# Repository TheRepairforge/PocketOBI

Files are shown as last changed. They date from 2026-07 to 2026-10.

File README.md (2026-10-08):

<div align="center">

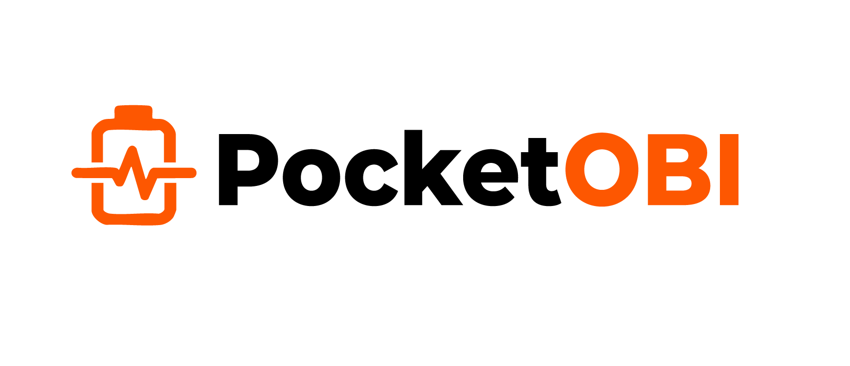
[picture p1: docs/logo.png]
PocketOBI logo


**A standalone, screen-based reader and diagnostic tool for Makita LXT (18V) batteries** — no PC required.






[Platform family](#platform-family) · [Watch it in action](#-watch-it-in-action) · [Status](#project-status) · [Features](#features) · [Hardware](#hardware) · [Build & flash](#build--flash) · [License](#license)

</div>

---

It reads cell voltages, temperatures, charge count and error/lock state, and
can reset false BMS lockouts to rescue packs that are still good.

PocketOBI is a standalone **OBI client**: it speaks the same Makita OneWire
protocol documented by the [Open Battery Information](https://github.com/mnh-jansson/open-battery-information)
project, but as a self-contained handheld device with a TFT screen and a
rotary encoder instead of a computer.

Created by **The Repair Forge** — follow the build on YouTube:
https://www.youtube.com/channel/UCQL_-pcIEkrDPyljl3QPzcw

## Platform family

PocketOBI started on Makita LXT (18V) — this repo — and is growing into a small
family of standalone OBI-client readers, one per battery platform. Same
hardware/UI approach, same protocol-first philosophy, different pack connector
and decode tables under the hood.

| Platform | Tag | Status |
|---|---|---|
| Makita LXT (18V) |  | ✅ shipping — this repo |
| Makita XGT (40V) |  | 🔜 planned |
| HiKOKI (BSL) |  | 🚧 in progress |

Each sibling gets its own repo once it's ready to publish; this table (and its
own release badge) grows as they ship.

## 📺 Watch it in action

PocketOBI v2 on YouTube (https://youtu.be/8Qe2dTXrJ8g)

The **v2** walkthrough — the new interface, the traffic-light verdict and the staged
repair wizard in action:
**https://youtu.be/8Qe2dTXrJ8g**

Original build & protocol deep-dive — how it works, the reverse-engineering, and a live demo:
**https://youtu.be/57KsQQ7-Qd0**

## Project status

Current release: **[v2.3.0](https://github.com/TheRepairforge/PocketOBI/releases/latest)** — see [CHANGELOG.md](CHANGELOG.md) for details.

The **v2** interface: a 2×2 launcher, a paged Battery view, a
traffic-light verdict and a staged Repair wizard, multilingual EN/FR/DE/ES, on a
single-source build. Validated on real BL18xx packs. Since **v2.2** the same firmware
also runs on the **CYD** (ESP32-2432S028R) with a touch UI, as an
[alternative board](#alternative-board-cyd-esp32-2432s028r). Since **v2.3** there is a
[Japanese build](#日本語--japanese--help-wanted) and every release ships ready-to-flash
binaries. Feedback and test reports
(especially serial logs from real packs) are very welcome.

> ⚠️ **Safety first.** These packs contain lithium cells and up to ~21 V on
> B+. **Never connect B+ to the ESP32.** Resetting a BMS error only helps a
> pack whose cells are actually healthy (a false lockout). Do **not** force a
> pack with a genuinely bad/low cell back into service — it is a fire risk.
> Use this tool at your own risk.

## Features

- **Standalone V2 interface** — a 2×2 launcher (Battery / Repair / Tools / About)
  driven by the rotary encoder (+ a secondary back button: short = back, long = home);
  it jumps straight to the Battery view when a pack is connected.
- **Battery view, paged** (turn the encoder): Overview / Health / Identity.
  - *Overview*: per-cell voltage bars (green / yellow / red), pack voltage, spread.
  - *Health*: our own cycle-based Condition estimate, over-discharge / over-load wear
    counters, cell min/max + spread, both temperature sensors + spread.
  - *Identity*: model, charge count, manufacturing date, capacity, and the pack
    **serial number** (ROM ID in Makita 16-char hex format).
- **Traffic-light verdict** — HEALTHY / REPAIRABLE / REAL FAULT (plus an orange
  "possible HW fix" tier). One verdict, computed from a single source and shown
  identically on the Battery tile, the screens and the Repair wizard.
- **Repair wizard** — a staged, feasibility-first check: comms → hardware faults
  (broken sense wire / weak group / imbalance / thermistor, each naming the group or
  sensor) → lock + prognosis (false lockout "should hold" vs a memorised fault
  "unlikely to hold"). A hardware fault blocks the unlock; the prognosis reads as
  guidance, never a guarantee.
- **Unlock / repair** — rewrites the frame to lift a *false* charger lockout on a
  pack whose cells are healthy: clears the charger-lock nybble, recomputes the
  charger-validated checksums, writes the frame back. Never forces a genuinely bad
  pack back into service. See below.
- **Error reset** with before → after feedback (full test-mode + power-cycle sequence).
- Automatic detection of standard vs older **F0513** BMS generations.
- **Multilingual UI** — English, French, German, Spanish, and **Japanese** in the
  Japanese build (see below).
- **PC bridge mode** — acts as a USB↔OneWire adapter (drop-in ArduinoOBI), so a desktop
  app works through PocketOBI: the original *Open Battery Information* app, or our own
  companion **[PackScope](https://github.com/TheRepairforge/PackScope)** — saved history,
  a health estimate and a guided repair workflow. Dual use: standalone tester **and** PC adapter.
- Tools: pack LED test, error reset, raw debug view (ROM ID + message frame).

## 日本語 / Japanese — help wanted

A **Japanese build** of the firmware shows the whole UI in Japanese (Settings → Language →
JA). Its text is a **first draft that no native speaker has reviewed**: expect stiff phrasing
and some wrong repair vocabulary. I do not read Japanese, so I cannot judge it myself.

**If you read Japanese and work on power tools or batteries, I would love your help.**
All the text is one file, [`strings_ja.h`](strings_ja.h): one line per message, with the English
next to it. Open a pull request, or an [issue](../../issues/new?template=translation.yml)
with corrections, no Git needed. You can see your text on every screen without a board with
[`tools/hostsim`](tools/hostsim/README.md). Rules and details: [docs/TRANSLATING.md](docs/TRANSLATING.md).

Build it with `pio run -e esp32-c3-ja` (or `cyd-ja`), or in the Arduino IDE by putting
`#define ENABLE_CJK 1` in a local `board_local.h` next to the sketch.

## Architecture

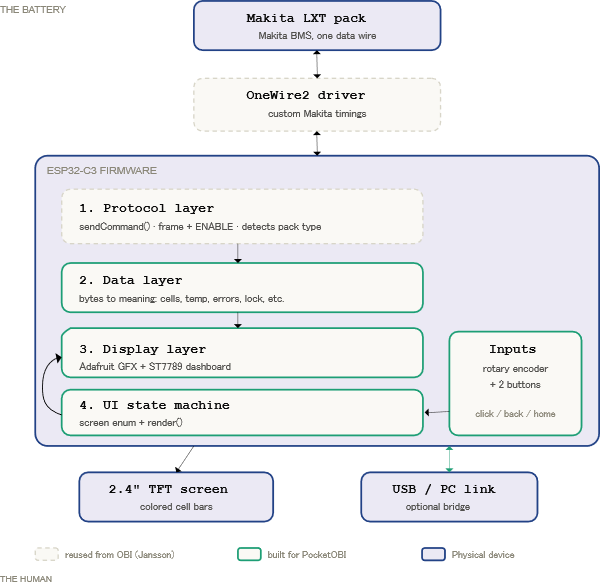
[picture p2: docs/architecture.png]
PocketOBI architecture diagram
[](docs/architecture.png)

*(click for full size — full-resolution file in [`docs/architecture.png`](docs/architecture.png))*

From the battery up: the Makita pack speaks over a single data wire; the bundled
**OneWire2** driver (reused from OBI) handles the custom Makita bit timings; the
ESP32-C3 firmware is layered — protocol (frames + ENABLE, pack-type detection),
data decode (bytes → cells / temperature / errors / lock), display (Adafruit GFX
+ ST7789) and a small UI state machine — driving the TFT and, optionally, a USB
PC bridge.

## Hardware

| Component | Notes |
|---|---|
| ESP32-C3 SuperMini | any ESP32-C3 board with native USB |
| 2.4" SPI TFT, ST7789 (240×320) | + integrated EC11 rotary encoder module |
| Makita BL1830 LXT adapter | clips onto the 18V pack |
| 2 × 470 Ω resistors | pull-ups for DATA and ENABLE (4.7 kΩ also works with short wiring) |
| USB-C power (power bank/charger) | powers the tool — NOT the battery |

### Wiring

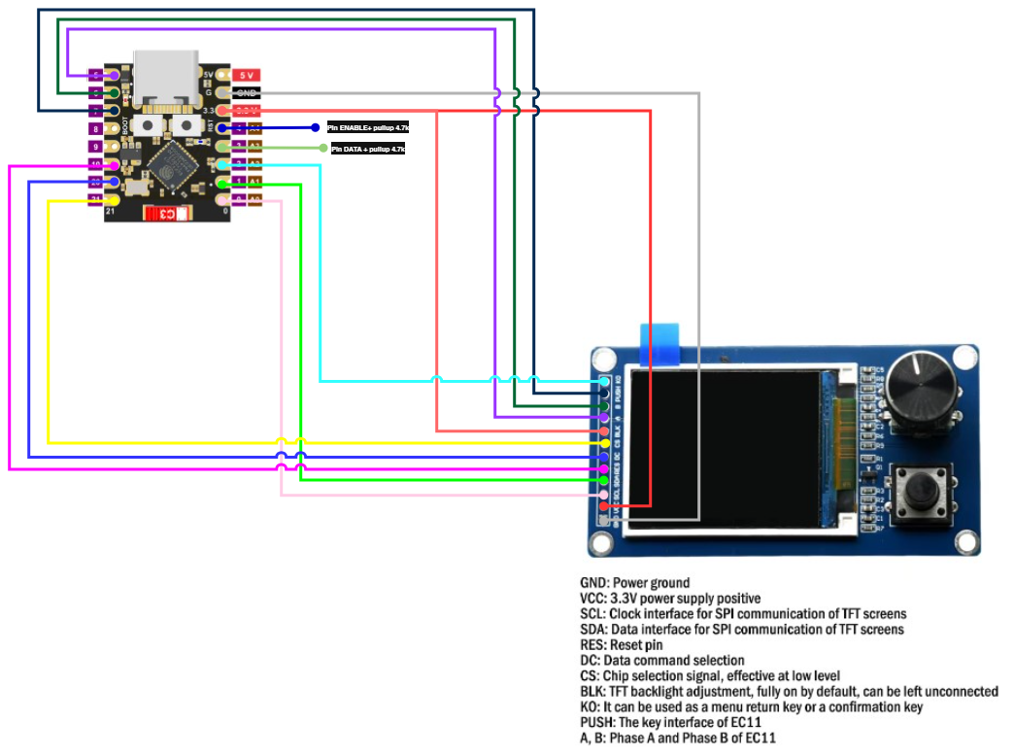
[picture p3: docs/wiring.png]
PocketOBI wiring diagram
[](docs/wiring.png)

*(click for full size — full-resolution file in [`docs/wiring.png`](docs/wiring.png))*

**Display + encoder module (2-in-1 TFT + EC11):**

| ESP32-C3 | Module pin | Role |
|---|---|---|
| GPIO0  | SCL  | SPI clock |
| GPIO1  | SDA  | SPI data (MOSI) |
| GPIO10 | RES  | reset |
| GPIO20 | DC | data / command select |
| GPIO21 | CS | chip select (active low) |
| 3.3 V  | VCC  | logic power |
| 3.3 V  | BLK  | backlight (or leave unconnected = always on) |
| GND | GND  | ground |
| GPIO5  | A | encoder phase A |
| GPIO6  | B | encoder phase B |
| GPIO7  | PUSH | encoder push button |
| GPIO2  | KO | secondary button (short = back, long = home) |

**Battery adapter (Makita LXT connector):**

| ESP32-C3 | Battery pin | Role |
|---|---|---|
| GPIO3 + 470 Ω pull-up to 3.3 V | Pin 2 — **DATA** | OneWire data |
| GPIO4 + 470 Ω pull-up to 3.3 V | Pin 6 — **ENABLE** | enable (active high) |
| GND | main **B-** terminal | ground (sturdier than signal pin 5; same ground) |
| — | Pin 1 — **B+ (18 V)** | **NEVER CONNECT** |

Notes:
- **Pull-ups:** **470 Ω** is the bench-validated value: on 3.3 V logic the pack
  loads the DATA line near the input threshold, and 4.7 kΩ was marginal with
  breadboard wiring. 4.7 kΩ (the upstream OBI value) should be fine with short,
  clean wiring. ENABLE is a driven output; 470 Ω there just keeps a single-value BOM.
- ⚠️ **Identify DATA/ENABLE by the ESP32 silkscreen labels ("3" / "4"), not by
  the adapter's connector position.** Some AliExpress adapters number their orange
  connector from the opposite end, so DATA can land on what looks like "plot 6"
  and ENABLE on "plot 2". Wrong plots = no comms (present = 0, all-`FF`/`00`).
- Power the tool from **USB-C**, never from the Makita pack (B+ is 18 V, and the
  BMS can cut its own output on error).

A carrier PCB has been **fabricated and bench-validated**. The fabrication files
(Gerbers, schematic PDF, BOM) and ordering notes are in [`hardware/`](hardware/); the
wiring and pinout reference stays in [HARDWARE.md](HARDWARE.md).

### Alternative board: CYD (ESP32-2432S028R)

Since v2.2 the firmware also builds for the "Cheap Yellow Display" (dual-USB / ST7789
revision, XPT2046 resistive touch). Same logic, same screens; the UI is driven by
touch instead of the encoder, with on-device touch calibration (Settings > Calibrate).
The ESP32-C3 build above remains the reference product.

The whole pack connection fits on the CYD's 4-pin **CN1** header:

| CN1 | Battery pin | Role |
|---|---|---|
| IO22 + 470 Ω pull-up to 3V3 | Pin 2 — **DATA** | OneWire data |
| IO27 + 470 Ω pull-up to 3V3 | Pin 6 — **ENABLE** | enable (active high) |
| GND | main **B-** terminal | ground |
| 3V3 | — | feeds the two pull-ups |
| — | Pin 1 — **B+ (18 V)** | **NEVER CONNECT** |

Step-by-step guide (build, flash, wiring, first read): [docs/CYD_GUIDE.md](docs/CYD_GUIDE.md).
Board selection and build notes: [CYD_NOTES.md](CYD_NOTES.md).

## Build & flash

### Flash a prebuilt binary (no build)

Each [release](https://github.com/TheRepairforge/PocketOBI/releases/latest) carries one
merged image per board and language, flashed at address `0x0`:

| File | Board |
|---|---|
| `PocketOBI-vX.Y.Z-esp32-c3.bin` | ESP32-C3 (the reference product) |
| `PocketOBI-vX.Y.Z-cyd.bin` | CYD (ESP32-2432S028R) |
| `PocketOBI-vX.Y.Z-esp32-c3-ja.bin` / `-cyd-ja.bin` | Same boards, Japanese build |
| `PocketOBI-vX.Y.Z-cyd-ili9341.bin` | CYD fitted with an ILI9341 panel (mirrored image on the plain CYD build, see the [CYD guide](docs/CYD_GUIDE.md)) |

```bash
pip install esptool
esptool --chip esp32c3 write_flash 0x0 PocketOBI-vX.Y.Z-esp32-c3.bin   # ESP32-C3
esptool --chip esp32 write_flash 0x0 PocketOBI-vX.Y.Z-cyd.bin          # CYD
```

Older esptool versions are called `esptool.py`. Check a download against `SHA256SUMS.txt`
from the same release. The `parts-*.zip` files hold the separate bootloader, partition
table and application images for tools that want them.

### Arduino IDE

1. Install the **ESP32 board package** (Espressif) via the Boards Manager.

   > **Use a stable core (3.x).** PocketOBI is built and tested against the
   > **stable ESP32 core 3.x** (2.0.x also works). Avoid the **alpha/dev
   > releases** (e.g. `4.0.0-alpha1`): they build fine but flood the console
   > with harmless `-Wdeprecated-declarations` / `-Wmissing-field-initializers`
   > warnings coming from *the core itself* (`esp32-hal-ledc.c`, `Esp.cpp`, …),
   > not from PocketOBI. If you see those warnings, it is the alpha core, not a
   > bug here — select a 3.x version in the Boards Manager.

2. Install these libraries via the Library Manager:
   - Adafruit GFX Library
   - Adafruit ST7735 and ST7789 Library
   - RotaryEncoder (by Matthias Hertel)
   - (OneWire2 is bundled in this repo — nothing to install.)
3. Open `PocketOBI/PocketOBI.ino`.
4. Board: **ESP32C3 Dev Module**, USB CDC On Boot: **Enabled**.
5. Upload.

**CYD build (Arduino IDE):** also install **XPT2046_Touchscreen** (Paul Stoffregen,
v1.4), select **ESP32 Dev Module**, and put a `board_local.h` next to the sketch
containing `#define POCKETOBI_BOARD BOARD_CYD` (the file is gitignored).

> Note: Arduino requires the sketch to live in a folder named `PocketOBI`.
> If you downloaded a ZIP (GitHub adds a `-main` suffix), rename the inner
> sketch folder back to `PocketOBI` before opening it.

### PlatformIO (VS Code)

The `platformio.ini` at the repo root builds the **same sources** the Arduino IDE
uses, straight from the sketch folder — no separate project, no copy to keep in sync:

```bash
pio run -e esp32-c3             # build the ESP32-C3 product
pio run -e esp32-c3 -t upload   # build + flash
pio run -e cyd -t upload        # CYD alternative board
pio device monitor              # serial monitor (115200)
```

There is one env per board; always pass `-e`, otherwise `pio run -t upload` builds and
flashes every env in turn. The `esp32-c3` env uses `esp32-c3-devkitm-1` (works for the
ESP32-C3 SuperMini); change `board` in that env for a different ESP32-C3 module.

## Usage

Power the tool over USB, connect DATA / ENABLE / GND to the pack (never B+),
and it reads automatically. Turn the encoder to navigate, click to select (on the CYD: tap).
If the home screen shows "No battery found", check wiring and use
Menu → Read battery. "Comm error" / all-`0xFF` means the pack's BMS is not
responding (dead, or not an OBI-compatible pack).

Trouble reading a pack, or connecting the PC bridge? See
**[TROUBLESHOOTING.md](TROUBLESHOOTING.md)** — a step-by-step guide to wiring,
no-comms and bridge-connection faults.

## Unlock / repair

Some packs refuse to charge even though their cells are healthy and balanced:
the BMS stores a frame that trips the charger's lock. The Makita charger only
validates **three** fields of the 32-byte frame:

- **nybble 34** (byte 17, low) — the charger lock, must be `0`;
- **CS0** (nybble 41) — `sum(nybbles 0–15) & 0x0F`;
- **CS2** (nybble 43) — `sum(nybbles 32–40) & 0x0F`.

The status byte (byte 19, e.g. `0xA5`) and the reported temperatures are **not**
part of that check. The battery's own internal lock additionally checks **CS1**
(nybbles 16–31, per the rosvall protocol docs), so the repair recomputes all
three checksums. The Unlock / repair menu entry clears nybble 34, recomputes
CS0/CS1/CS2, writes the frame back (arm → write → store) and clears the internal
error register. The failure code (nybble 40, e.g. `0xF` = dead) is **never**
cleared — a genuinely dead pack is not forced back into service. Manufacturing/status bytes are never touched, and if the frame
is already valid no write is performed.

> ⚠️ This **writes to the BMS flash** and is gated behind a confirmation screen.
> It only clears a *false* charger lockout on an otherwise-healthy pack; it never
> overrides the BMS's own fault protection. Never use it to force a pack with a
> bad or low cell back into service.

## Note on temperature units

Temperatures are decoded as **1/10 K** (`T_C = raw / 10 - 273.15`). This is now
corroborated by four independent sources: the
[rosvall protocol docs](https://codeberg.org/rosvall/makita-lxt-protocol), the
obi-esp32 encoding, and both sides of the
[m5din-makita](https://github.com/no-body-in-particular/m5din-makita) fork — its
reader (`(raw / 10) - 273.15`) *and* its BMS emulator (`(T_C + 273.15) * 10`).
The original Open Battery Information app decodes the same field as
**Celsius x100**; that appears to be the outlier. The unit is still not stated in
any official Makita document, so treat the absolute value as approximate, but the
1/10 K interpretation is the well-supported one. The dependable signal is *relative*: the
two sensors are shown side by side (e.g. `28/31`, and in red when a value is
implausible), so a reading that is far off or that disagrees strongly with the
other flags a likely faulty thermistor.

The two sensors are reported by the BMS over the data line (there is **no
separate thermistor pin** on the connector). The original protocol simply labels
them **"Sensor 1"** and **"Sensor 2"** — **which reading is the cell sensor vs the
MOSFET sensor is not documented**, and their physical placement on the BMS board
is unknown. PocketOBI just shows both values; do not assume which is which.

## Versioning

See [CHANGELOG.md](CHANGELOG.md). The current version is shown on the
Version / info screen and defined as `FW_VERSION` in `pocketobi.h`.

## Credits

- **Open Battery Information** by **Martin Jansson** — the original project that
  documents the Makita protocol and provides the OneWire2 library.
  https://github.com/mnh-jansson/open-battery-information (MIT)
- ESP32-C3 wiring reference: the `obi-esp32` port by appositeit.
- Root protocol reverse-engineering: the
  [rosvall/makita-lxt-protocol](https://codeberg.org/rosvall/makita-lxt-protocol)
  documentation (frame byte/nybble map, the three checksum ranges, per-type
  command sets) — the origin much of the LXT decoding traces back to.
- Unlock / frame-repair research: the
  [synrais/Makita-LXT-Battery-Monitor-Unlocker](https://github.com/synrais/Makita-LXT-Battery-Monitor-Unlocker)
  project, which documented the frame byte map, the CS0/CS2 checksums, the
  charger-lock nybble and the arm/write/store opcodes. That repository ships with
  **no license** (all rights reserved), so **none of its code is used here**;
  PocketOBI's unlock feature is a clean-room reimplementation from those
  (unprotectable) protocol facts only, cross-checked against real battery dumps.

## License

PocketOBI is licensed under the **PolyForm Noncommercial License 1.0.0** — free to
use, modify, and share for any **noncommercial** purpose (personal, hobby, repair,
education, research). Commercial use requires a separate license. See [LICENSE](LICENSE).

Bundled and reused third-party components keep their own licenses — see
[THIRD-PARTY.md](THIRD-PARTY.md). The bundled OneWire2 library and the upstream
Open Battery Information project remain under the MIT license.

---

<div align="center">

```
  ___         _       _    ___  ___ ___ 
 | _ \___  __| |_____| |_ / _ \| _ )_ _|
 |  _/ _ \/ _| / / -_)  _| (_) | _ \| | 
 |_| \___/\__|_\_\___|\__|\___/|___/___|
=-=-=-=-=-=-=-=-=-=-=-=-=-=-=-=-=-=-=-=-=-=-=
       . No Guru Meditation required .
=-=-=-=-=-=-=-=-=-=-=-=-=-=-=-=-=-=-=-=-=-=-=
```

Built by **[The Repair Forge](https://www.youtube.com/channel/UCQL_-pcIEkrDPyljl3QPzcw)**

</div>

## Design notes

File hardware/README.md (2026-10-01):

# PocketOBI — hardware

Fabrication files for the PocketOBI carrier PCB: a small 2-layer board that carries the
ESP32-C3 SuperMini, the display + encoder module header, the Makita LXT battery connector
and the two pull-up resistors. **This is the board only — it does not restate the
wiring/pinout, which lives in [`../HARDWARE.md`](../HARDWARE.md) and the main
[README](../README.md).**

> ⚠️ Same safety rule as the firmware: **never connect battery B+ (18 V) to the ESP32.**

## Revision

First fabricated and **bench-validated** revision — Gerbers dated **2026-08-05**
(`gerber/PocketOBI-HW-gerbers-2026-08-05.zip`). This is the exact set that was ordered.

> **Schematic PDF updated 2026-09-30; PCB and Gerbers unchanged.**

## What's here

| File | What it is |
|---|---|
| `gerber/PocketOBI-HW-gerbers-2026-08-05.zip` | ready-to-order Gerbers + drill — upload this |
| `gerber/*.gbr`, `*.drl` | the same layers, extracted, for inspection |
| `PocketOBI-HW-schematic.pdf` | the schematic — to read and troubleshoot, not editable |
| `PocketOBI-HW-BOM.csv` | bill of materials (6 parts) |

## Order the board

Upload `gerber/PocketOBI-HW-gerbers-2026-08-05.zip` to a fab house (JLCPCB, PCBWay, …).
Defaults are fine: **2 layers**, 1.6 mm, HASL, any colour — no controlled impedance and no
special stackup.

## Bill of materials

| Ref | Part | Note |
|---|---|---|
| U1 | ESP32-C3 SuperMini | any ESP32-C3 board with native USB |
| M1 | 1×12 pin socket, 2.54 mm | header for the 2-in-1 TFT + EC11 module |
| Battery_Interface1 | JST-PH 6-pin, vertical | to the Makita LXT adapter |
| Battery_GND1 | 2-pin screw terminal, 3.5 mm | battery B- |
| R1, R2 | 4.7 kΩ resistor, THT | DATA and ENABLE pull-ups (470 Ω also works) |

Full list: [`PocketOBI-HW-BOM.csv`](PocketOBI-HW-BOM.csv). Everything is through-hole and
hand-solderable. (R1/R2 export as a generic value `R` in the CSV — they are **4.7 kΩ**.)

## Assembly

Solder the through-hole parts, then seat the ESP32-C3 and the display + encoder module on
the headers. **Wiring, pinout and the DATA/ENABLE identification gotcha are in
[`../HARDWARE.md`](../HARDWARE.md)** — not repeated here so the two never drift.

## Enclosure

A 3D-printable enclosure is on Printables:
**<https://www.printables.com/model/1833871-pocketobi-makita-18v-lxt-battery-diagnostic-tool-c>**
— "PocketOBI – Makita 18V LXT Battery Diagnostic Tool", by The Repair Forge. The STL files
are not committed here; download them from the Printables page.

## License

The hardware design files in this folder (Gerbers, schematic, BOM) are licensed
**CC BY-NC-SA 4.0** — see [LICENSE](LICENSE). The firmware is licensed separately under the
PolyForm Noncommercial License 1.0.0 (PolyForm is a software licence, so the board files use
the Creative Commons equivalent).

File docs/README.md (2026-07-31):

# docs

Images referenced by the main [README](../README.md).

Place these two files here, with **exactly** these names:

- **`architecture.png`** — the software / architecture block diagram
  (battery → OneWire2 → firmware layers → screen / PC link).
- **`wiring.png`** — the physical wiring diagram
  (ESP32-C3 SuperMini ↔ 2.4" TFT + EC11 module, with the DATA/ENABLE pull-ups).

Any resolution works; the README shows them as clickable thumbnails that open the
full-size file. Prefer PNG for crisp diagrams.

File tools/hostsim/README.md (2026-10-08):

# hostsim: PocketOBI screens on your PC

Renders every screen of the firmware, in every language, as PNG images, **without a
board**. It compiles the real UI code (`display.cpp`, `cjk_render.cpp`, the string
tables, ...) for the PC against the real Adafruit_GFX library. The images are what the
device draws, pixel for pixel: same fonts, same coordinates, same clipping.

Use it to:
- check that a translation fits (Japanese especially, see `docs/TRANSLATING.md`);
- preview a UI change before flashing;
- make screenshots for the README or a video.

## Run

```
pip install pillow ziglang                 # once: image library + a C++ compiler
python tools/hostsim/hostsim.py            # EN / FR / DE / ES
python tools/hostsim/hostsim.py --ja       # same + Japanese (ENABLE_CJK=1 build)
python tools/hostsim/hostsim.py --ja --board cyd --scale 2
```

Output, regenerated on each run and not committed:

```
tools/hostsim/out/<board>[-ja]/sheet_<LANG>.png        all screens on one page
tools/hostsim/out/<board>[-ja]/<LANG>/<nn>_<screen>.png one image per screen
```

You also need the **Adafruit GFX Library**. If you have built PocketOBI with the Arduino
IDE or PlatformIO it is already installed and found automatically; otherwise pass
`--gfx <folder>`. Any C++17 compiler works in place of zig: `--cxx g++`.

## How it works

| File | Role |
|---|---|
| `shim/` | Fakes of the hardware-facing libraries: `Adafruit_ST7789` is a `GFXcanvas16` RAM framebuffer; GPIO, `Serial`, preferences, encoder, touch and the battery bus do nothing; time only advances when the code waits. |
| `hostsim_main.cpp` | Loads a fixture pack (illustrative values, not a real capture), sets the navigation state of each screen, calls the firmware's `render()`, saves the frame. |
| `hostsim.py` | Finds the compiler and Adafruit_GFX, builds, runs, converts to PNG, makes the contact sheets. |

To add a screen or a scenario (for example a locked pack), add a line to `SCREENS` in
`hostsim_main.cpp`.

**Every `.cpp` here is wrapped whole in `#ifdef POCKETOBI_HOSTSIM`.** PlatformIO compiles
every source file under the repository root (`src_dir = .`), this folder included; the
guard makes these files empty in a firmware build. Keep it on any new `.cpp`, and never
copy a `shim/` header to the repository root, where it would hide the real library.

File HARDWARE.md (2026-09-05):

# PocketOBI — Hardware / PCB notes

This document describes the interconnect ("carrier") PCB for PocketOBI so it can
be recreated in KiCad. **Status: PCB not manufactured yet, but the wiring below
is VALIDATED** — it reads a real BL1860B correctly (2026-07).

Validated battery wiring (adapter's orange 7-position connector): **GPIO3 = DATA <-
orange plot 6** (470 ohm pull-up = R1), **GPIO4 = ENABLE <- orange plot 2** (470 ohm
pull-up = R2), **GND from the main B- terminal** (orange plot 1 unused). Identify
the ESP32 pins by their silkscreen label ("3"/"4"), NOT by position. This adapter
numbers its orange connector from the opposite end vs the canonical Makita pins.
On 3.3 V logic the DATA read line needed a lower pull-up (470 ohm worked); 4.7 k is
the reference value and may also work with the PCB's short/clean traces — keep the
DATA pull-up (R1) low if reads are flaky.

The two active parts (ESP32-C3 SuperMini and the ST7789 + EC11 module) are
ready-made boards. The PCB is just a **carrier**: it sockets both modules,
carries the two pull-up resistors, and breaks out the battery connector.

> ⚠️ **Safety:** the battery's B+ (up to ~21 V) is NEVER routed on this board.
> Only DATA, ENABLE and GND (from the B- terminal) come from the pack.

## Components (BOM)

| Ref | Part | Qty | Notes |
|-----|---|-----|---|
| U1 | ESP32-C3 SuperMini | 1 | socketed on female headers |
| M1 | 2.4" ST7789 TFT + EC11 encoder module | 1 | the 12-pin 2-in-1 module |
| R1, R2 | 470 Ω resistor | 2 | single value for both pull-ups (see note) |
| J1 | female header, matches U1 | 1–2 | 2.54 mm pitch |
| J2 | female header, matches M1 | 1 | 2.54 mm pitch, 12 pins |
| J3 | JST-PH 6-pin, board header (B6B-PH-K, top entry) | 1 | battery signal plug; only 2 pins used |
| J4 | screw terminal 2-pin, 3.5 mm | 1 | battery GND wire from the B- terminal |
| PCB | 2-layer | 1 | ~JLCPCB/PCBWay |

## Module pin reference

**M1 (display + encoder module)** header, 12 pins:
`GND, VCC, SCL, SDA, RES, DC, CS, BLK, KO, PUSH, A, B`
- SCL = SPI clock, SDA = SPI MOSI.
- KO = secondary button, PUSH = encoder button, A/B = encoder phases.
- The buttons and encoder common are referenced to the module's GND internally,
  so only the signal pins go to the ESP32 (firmware uses internal pull-ups).

**U1 (ESP32-C3 SuperMini)** — connect by GPIO name; the physical pin order
depends on your board, so **check the silkscreen** of your exact SuperMini.

## Netlist (connection map)

Each line is one electrical net = everything that must be joined together.

```
NET 3V3      : U1.3V3, M1.VCC, M1.BLK, R1.p1, R2.p1
NET GND      : U1.GND, M1.GND, J4.p1           ; GND wire from the battery B- terminal
NET SPI_SCLK : U1.GPIO0, M1.SCL
NET SPI_MOSI : U1.GPIO1, M1.SDA
NET TFT_RES  : U1.GPIO10, M1.RES
NET TFT_DC   : U1.GPIO20, M1.DC
NET TFT_CS   : U1.GPIO21, M1.CS
NET ENC_A    : U1.GPIO5, M1.A
NET ENC_B    : U1.GPIO6, M1.B
NET ENC_PUSH : U1.GPIO7, M1.PUSH
NET BACK_KO  : U1.GPIO2, M1.KO
NET DATA     : U1.GPIO3, R1.p2, J3.p1          ; OneWire data (JST pin 1), pull-up via R1
NET ENABLE   : U1.GPIO4, R2.p2, J3.p5          ; enable (JST pin 5), pull-up via R2
No-Connect   : J3.p2, J3.p3, J3.p4, J3.p6      ; unused JST pins (incl. battery B-/signal GND)
```

Battery JST-PH pin map (adapter omits B+, so JST pin N = battery pin N+1):
- J3.p1 = battery pin 2 = **DATA** (used)
- J3.p5 = battery pin 6 = **ENABLE** (used)
- J3.p2/p3/p4/p6 = battery pins 3/4/5/7 = unused here (p4 = signal GND, p6 = B-)

Notes:
- Ground is brought in separately on **J4** from the main battery **B-** terminal
  (user's choice: sturdier than the small signal pins). Common ground between the
  ESP32 and the pack is **mandatory** for communication.
- R1 pulls DATA up to 3V3, R2 pulls ENABLE up to 3V3. **Both 470 Ω** (single BOM
  value). DATA *needs* the stronger 470 Ω (the pack loads the line near the 3.3 V
  input threshold); ENABLE's pull-up value is non-critical (ENABLE is a driven
  output), so it uses 470 Ω too for uniformity. Both resistors required.
- **No B+ (18 V) anywhere on this board** — the adapter does not route it into the
  JST, and we do not wire it. Put No-Connect flags on the unused JST pins.
- M1.BLK tied to 3V3 = backlight always on.

## Suggested footprints

| Ref | Footprint | Note |
|-----|---|---|
| U1 | 2× pin header 2.54 mm (or a community "ESP32-C3 SuperMini" footprint) | verify pin count/row spacing on your board |
| M1 | 1×12 pin header 2.54 mm | verify count/pitch/order on your module |
| R1, R2 | R_0805 (SMD) or R_Axial_DIN0207 (through-hole) | beginner: through-hole is easier to hand-solder |
| J3 | `Connector_JST:JST_PH_B6B-PH-K_1x06_P2.00mm_Vertical` (top entry; or `S6B-PH-K ..._Horizontal` for side entry) | matches the battery signal plug |
| J4 | `TerminalBlock_Phoenix:TerminalBlock_Phoenix_MC-1,5-2-3.5_1x02_P3.50mm` (or any 2-pin 3.5 mm you have) | GND wire from B-; wire horizontal / screw on top |

## Placement / routing guidelines

- Put J3 (battery) at one board edge, away from the ESP32; silkscreen-label
  DATA / ENABLE / GND, and add a "DO NOT CONNECT B+" note.
- Place R1/R2 next to the ESP32 GPIO3/GPIO4 pins.
- 2-layer board: pour a GND copper fill on the bottom layer, tied to NET GND.
- SPI speed is modest; trace lengths are not critical, just keep them tidy.
- Socket both modules on female headers so they stay removable/repairable.

## KiCad quick-start (absolute beginner)

1. Install **KiCad 9** from kicad.org. Open it, **File → New Project**.
2. **Schematic Editor**: place the parts (`A` to add a symbol):
   - Generic headers for U1, M1, J3 (e.g. `Conn_01x12` for M1). It's fine to use
     plain connector symbols for a carrier board.
   - Two resistors `R` for R1, R2.
3. **Wire it with net labels** (easiest method): instead of drawing wires
   everywhere, put a **net label** (shortcut `L`) on each pin using the names
   from the netlist above. KiCad connects pins that share a label. This turns
   the netlist above directly into your schematic.
4. **Assign footprints**: Tools → *Assign Footprints*, pick from the table above.
5. **PCB Editor**: *Update PCB from Schematic* (`F8`), place the parts, draw the
   board outline (Edge.Cuts), then **route** the tracks (the thin "ratsnest"
   lines show what to connect). Add a GND copper pour.
6. Run **DRC** (Design Rule Check) and fix any errors.
7. **Plot / Fabrication Outputs** → Gerbers + drill files → zip → send to a
   fab house (JLCPCB / PCBWay).

## Fabrication / JLCPCB export (KiCad 10)

Exact workflow for this 2-layer, hand-assembled board (no stencil).

**`File → Plot` — enable exactly these layers:**
`F.Cu`, `B.Cu`, `F.Silkscreen`, `B.Silkscreen`, `F.Mask`, `B.Mask`, `Edge.Cuts`.
Skip `F.Paste`/`B.Paste` (only needed for a stencil) and `F.Fab`/`B.Fab`/`User.*`.

**Plot options:** format `Gerber`; Output directory `gerbers/`; Drill marks `None`;
Scaling `1:1`; Plot mode `Filled`; keep **Plot reference designators** on; coordinate
format `4.6 mm`; leave **Use extended X2 format** at the KiCad default. Click **Plot**.

**Drill files — `Generate Drill Files…`:** format `Excellon`; tick **Merge PTH and
NPTH into one file**; Units `Millimeters`; Drill origin `Absolute`; Map file `None`.
Click **Generate Drill File**.

**Files produced in `gerbers/` (zip them together, files at the zip root):**

```
PocketOBI-F_Cu.gbr          front copper
PocketOBI-B_Cu.gbr          back copper
PocketOBI-F_Silkscreen.gbr  front silkscreen
PocketOBI-B_Silkscreen.gbr  back silkscreen
PocketOBI-F_Mask.gbr        front soldermask
PocketOBI-B_Mask.gbr        back soldermask
PocketOBI-Edge_Cuts.gbr     board outline
PocketOBI.drl               drills (PTH + NPTH merged)
```

**Upload:** zip → jlcpcb.com → *Add gerber file*; check the preview (outline, 2 layers
detected, silkscreen legible). Order settings: **Layers = 2**, thickness **1.6 mm**,
rest default.

**Before upload:** open the `gerbers/` folder in **GerbView** (KiCad's Gerber viewer)
for a final visual sanity check — what you see there is what the fab receives.

## Recommended path

The battery communication is validated on real hardware; still, it is wise to
freeze the wiring on a **perfboard** first, then commit to this PCB.

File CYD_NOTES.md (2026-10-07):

# PocketOBI on the CYD (alternative board)

**New to this? Start with the step-by-step guide: [docs/CYD_GUIDE.md](docs/CYD_GUIDE.md)**
(install, build, flash, wiring, first read, troubleshooting).

The **CYD** (ESP32-2432S028R, dual-USB / ST7789 revision, XPT2046 resistive touch) is an
**alternative** board, supported since v2.2.0. The reference product is the ESP32-C3 +
ST7789 + EC11 encoder — see `HARDWARE.md`.

**Selecting the CYD build:** the board is chosen at build time. The pin map and the
board-select mechanism live in `board_config.h`; `platformio.ini` has one env per board
(`pio run -e cyd`). To build the CYD from the Arduino IDE, drop a gitignored
`board_local.h` next to the sketch containing `#define POCKETOBI_BOARD BOARD_CYD`. The
logic branches only on the `BOARD_HAS_ENCODER` / `BOARD_HAS_TOUCH` capability flags, never
on the board id.

**Status:** the CYD is **bench-validated end to end**: the touch UI and a real pack read
over the CN1 connector both work on hardware. The CN1 wiring (DATA = IO22, ENABLE = IO27,
470 Ω pull-ups to 3V3, GND to B-, never B+) is in the README, section
"Alternative board: CYD".

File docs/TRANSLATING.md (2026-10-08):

# Translating PocketOBI

PocketOBI's screens exist in English, French, German, Spanish and Japanese. English and French
are written by the maintainer; **German, Spanish and Japanese are first drafts that no native
speaker has checked yet.** If you speak one of them, your corrections are very welcome.

| Language | File | Notes |
|---|---|---|
| English, French, German, Spanish | `strings_i18n.h` (`STRTAB`) | ASCII only: the device fonts have no accents (FR/ES accents dropped, German umlauts written ae/oe/ue/ss) |
| Japanese | `strings_ja.h` (`STRTAB_JA`) | Only in the Japanese build (`ENABLE_CJK=1`), drawn with 16x16 bitmap glyphs |

English is the reference. The language is chosen on the device in **Settings > Language**.

## German and Spanish: the easy way

Open the review page for your language: https://therepairforge.github.io/translate/

It shows every device screen in your language and lists every string. Next to each one,
**Suggest a fix** opens a GitHub issue already filled in (language, key, English, current
text): you only type your version.

For a full pass, download the spreadsheet from the same page, fill the `your_suggestion`
column, and attach the file to a [translation issue](https://github.com/TheRepairforge/PocketOBI/issues/new?template=translation.yml).

### Two limits of the device screen

- **Plain ASCII only.** The screen fonts have no accented letters: write `Reparer`, `Bateria`,
  and German umlauts as `ae`, `oe`, `ue`, `ss`.
- **Limited width.** Keep a fix close to the longest version shown today (the review page
  gives the number of characters). Every accepted fix is rendered on the real screen before it
  ships, so nothing ends up cut off.

All these strings are in [`strings_i18n.h`](../strings_i18n.h), one row per string, one column
per language. Pull requests that edit that table directly are welcome too, but an issue is
enough.

## Japanese: help wanted

The Japanese text is a **best-effort draft written without a native speaker**. It is
published that way on purpose, so it can be corrected by the people who use it. If you
read Japanese, and especially if you repair or use power-tool batteries, a review is the
most useful contribution you can make.

A string left as `nullptr` shows the English text. A few technical screens (Debug, the
touch calibration) and the credits stay in English in every language.

### See your text on the screens (no board needed)

```
pip install pillow ziglang
python tools/hostsim/hostsim.py --ja
```

This compiles the real firmware for your PC and saves every screen as an image, in
`tools/hostsim/out/c3-ja/` (`sheet_JA.png` shows them all on one page). Details:
[`tools/hostsim/README.md`](../tools/hostsim/README.md).

### Fixing or improving a translation (no code needed)

1. Open `strings_ja.h`. Each line is one message, with the English source as a comment:

   ```c
   /*S_TEMP*/     "温度",    // EN: "Temp"
   /*S_CONDITION*/ nullptr,  // EN: "Condition"
   ```

2. Replace the text between the quotes, or replace `nullptr` with `"your text"`.
   Never change the `/*S_...*/` label or the order of the lines.
3. Open a pull request, or paste your corrections in a
   [translation issue](https://github.com/TheRepairforge/PocketOBI/issues/new?template=translation.yml) (key + better text).
   You do not need to build anything; the maintainer regenerates the glyphs.

### Rules that keep the device from breaking

- **Keep the placeholders exactly** (`%d`, `%s`, `%.1f`, ...), in the same order as English.
- **Short.** The screen is 320 px wide. A Japanese character is 13 to 17 px wide depending
  on the text size, so a line fits 18 to 24 characters; labels next to a value have much
  less room. Check with hostsim. The firmware also limits a string to 63 bytes (a Japanese
  character takes 3), and `tools/gen_cjk_glyphs.py` refuses a longer one.
- Labels are short noun phrases. Full sentences (hints, repair advice) can use です・ます.
- Japanese characters, ASCII letters and digits are fine. Avoid half-width katakana and
  emoji: there is no glyph for them.

The PackScope desktop app has its own Japanese catalog and a glossary of the battery terms
it uses; keeping both consistent helps users who use the two together.

## For maintainers: after editing `strings_ja.h`

```
python tools/gen_cjk_glyphs.py            # check the table + regenerate glyphs_ja.h
pio run -e esp32-c3-ja                    # or cyd-ja
```

The script stops with an error if `strings_ja.h` no longer has one line per message, in
the order of `enum StrId`. A character missing from `glyphs_ja.h` draws as a hollow box on
the device, so a forgotten regeneration is visible. In the Arduino IDE, put
`#define ENABLE_CJK 1` in the local, untracked `board_local.h` instead of using `-D`.

**Fonts.** The glyphs are rasterised from two fonts under the SIL Open Font License:
**Noto Sans JP Medium** for the 16 px cell, **Fusion Pixel 12px** (Japanese variant), a pixel
font drawn for that grid, for the 12 px cell. Download the two `.otf` files once into
`tools/.fonts/` (links at the top of `tools/gen_cjk_glyphs.py`). Without them the script
falls back to a Windows font, which is not redistributable: never commit that output.

## Credit

Tell us in the issue how you want to be thanked in the release notes, or leave it empty to
stay anonymous.

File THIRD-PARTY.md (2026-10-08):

# Third-party notices

PocketOBI itself is licensed under the PolyForm Noncommercial License 1.0.0 (see
[LICENSE](LICENSE)). The following third-party components are bundled in or reused
by PocketOBI and remain under their own licenses. PolyForm Noncommercial does **not**
apply to them.

--------------------------------------------------------------------------------

## OneWire2 (bundled: `OneWire2.h`, `OneWire2.cpp`, `util/`)

A modified version of the OneWire library, taken from the Open Battery Information
project. Licensed under the MIT license. Original copyright and permission notices
are retained in the source files.

  Copyright (c) 2007 Jim Studt and contributors
  Maintained since 2010 by Paul Stoffregen (paul@pjrc.com)
  Bit-level timing modifications from the Open Battery Information project

## Open Battery Information (base project / protocol implementation)

PocketOBI builds on the Open Battery Information project by Martin Jansson, from
which the OneWire2 library and the reference protocol implementation come.
Licensed under the MIT license.

  https://github.com/mnh-jansson/open-battery-information
  Copyright (c) 2024 Martin Jansson

--------------------------------------------------------------------------------

## MIT License

The MIT license below applies to the OneWire2 library and to the Open Battery
Information project listed above (each with its own copyright holder as noted).

Permission is hereby granted, free of charge, to any person obtaining a copy
of this software and associated documentation files (the "Software"), to deal
in the Software without restriction, including without limitation the rights
to use, copy, modify, merge, publish, distribute, sublicense, and/or sell
copies of the Software, and to permit persons to whom the Software is
furnished to do so, subject to the following conditions:

The above copyright notice and this permission notice shall be included in all
copies or substantial portions of the Software.

THE SOFTWARE IS PROVIDED "AS IS", WITHOUT WARRANTY OF ANY KIND, EXPRESS OR
IMPLIED, INCLUDING BUT NOT LIMITED TO THE WARRANTIES OF MERCHANTABILITY,
FITNESS FOR A PARTICULAR PURPOSE AND NONINFRINGEMENT. IN NO EVENT SHALL THE
AUTHORS OR COPYRIGHT HOLDERS BE LIABLE FOR ANY CLAIM, DAMAGES OR OTHER
LIABILITY, WHETHER IN AN ACTION OF CONTRACT, TORT OR OTHERWISE, ARISING FROM,
OUT OF OR IN CONNECTION WITH THE SOFTWARE OR THE USE OR OTHER DEALINGS IN THE
SOFTWARE.

--------------------------------------------------------------------------------

## Noto Sans CJK JP and Fusion Pixel (glyph bitmaps in `glyphs_ja.h`, Japanese build only)

The Japanese characters of the `ENABLE_CJK` build are 1-bit bitmaps rasterised by
`tools/gen_cjk_glyphs.py`: the 16 px cell from Noto Sans JP Medium (Noto Sans CJK,
version 2.004), the 12 px cell from Fusion Pixel 12px monospaced, Japanese variant
(release 2026.09.25). They are a modified form of the fonts and stay under the SIL Open
Font License 1.1, reproduced below. The default (non-Japanese) build contains none of them.

  https://github.com/notofonts/noto-cjk
  Copyright 2014-2021 Adobe (http://www.adobe.com/). Noto is a trademark of Google Inc.

  https://github.com/TakWolf/fusion-pixel-font
  Copyright (c) 2022, TakWolf (https://takwolf.com).
  Fusion Pixel merges glyphs from Ark Pixel Font (Copyright (c) 2021, TakWolf), Cubic 11
  (Copyright (c) 2005 M+ FONTS PROJECT, (C) 2002-2004 COZ) and Galmuri (Copyright (c)
  2019-2025 Lee Minseo), all under the SIL Open Font License 1.1.

--------------------------------------------------------------------------------

## Acknowledgements (facts / documentation only — no code reused)

The Makita LXT protocol facts that PocketOBI reimplements independently are
documented by several community projects. These contributed knowledge, not code,
and impose no licensing obligation; they are credited with thanks in the README
(e.g. rosvall/makita-lxt-protocol, drakosha/makita-battery-tools). Where any such
project ships without a license, none of its code is used here.

--------------------------------------------------------------------------------

## SIL Open Font License 1.1 (applies to the Noto Sans CJK JP and Fusion Pixel glyphs above)

This Font Software is licensed under the SIL Open Font License,
Version 1.1.

This license is copied below, and is also available with a FAQ at:
http://scripts.sil.org/OFL

-----------------------------------------------------------
SIL OPEN FONT LICENSE Version 1.1 - 26 February 2007
-----------------------------------------------------------

PREAMBLE
The goals of the Open Font License (OFL) are to stimulate worldwide
development of collaborative font projects, to support the font
creation efforts of academic and linguistic communities, and to
provide a free and open framework in which fonts may be shared and
improved in partnership with others.

The OFL allows the licensed fonts to be used, studied, modified and
redistributed freely as long as they are not sold by themselves. The
fonts, including any derivative works, can be bundled, embedded,
redistributed and/or sold with any software provided that any reserved
names are not used by derivative works. The fonts and derivatives,
however, cannot be released under any other type of license. The
requirement for fonts to remain under this license does not apply to
any document created using the fonts or their derivatives.

DEFINITIONS
"Font Software" refers to the set of files released by the Copyright
Holder(s) under this license and clearly marked as such. This may
include source files, build scripts and documentation.

"Reserved Font Name" refers to any names specified as such after the
copyright statement(s).

"Original Version" refers to the collection of Font Software
components as distributed by the Copyright Holder(s).

"Modified Version" refers to any derivative made by adding to,
deleting, or substituting -- in part or in whole -- any of the
components of the Original Version, by changing formats or by porting
the Font Software to a new environment.

"Author" refers to any designer, engineer, programmer, technical
writer or other person who contributed to the Font Software.

PERMISSION & CONDITIONS
Permission is hereby granted, free of charge, to any person obtaining
a copy of the Font Software, to use, study, copy, merge, embed,
modify, redistribute, and sell modified and unmodified copies of the
Font Software, subject to the following conditions:

1) Neither the Font Software nor any of its individual components, in
Original or Modified Versions, may be sold by itself.

2) Original or Modified Versions of the Font Software may be bundled,
redistributed and/or sold with any software, provided that each copy
contains the above copyright notice and this license. These can be
included either as stand-alone text files, human-readable headers or
in the appropriate machine-readable metadata fields within text or
binary files as long as those fields can be easily viewed by the user.

3) No Modified Version of the Font Software may use the Reserved Font
Name(s) unless explicit written permission is granted by the
corresponding Copyright Holder. This restriction only applies to the
primary font name as presented to the users.

4) The name(s) of the Copyright Holder(s) or the Author(s) of the Font
Software shall not be used to promote, endorse or advertise any
Modified Version, except to acknowledge the contribution(s) of the
Copyright Holder(s) and the Author(s) or with their explicit written
permission.

5) The Font Software, modified or unmodified, in part or in whole,
must be distributed entirely under this license, and must not be
distributed under any other license. The requirement for fonts to
remain under this license does not apply to any document created using
the Font Software.

TERMINATION
This license becomes null and void if any of the above conditions are
not met.

DISCLAIMER
THE FONT SOFTWARE IS PROVIDED "AS IS", WITHOUT WARRANTY OF ANY KIND,
EXPRESS OR IMPLIED, INCLUDING BUT NOT LIMITED TO ANY WARRANTIES OF
MERCHANTABILITY, FITNESS FOR A PARTICULAR PURPOSE AND NONINFRINGEMENT
OF COPYRIGHT, PATENT, TRADEMARK, OR OTHER RIGHT. IN NO EVENT SHALL THE
COPYRIGHT HOLDER BE LIABLE FOR ANY CLAIM, DAMAGES OR OTHER LIABILITY,
INCLUDING ANY GENERAL, SPECIAL, INDIRECT, INCIDENTAL, OR CONSEQUENTIAL
DAMAGES, WHETHER IN AN ACTION OF CONTRACT, TORT OR OTHERWISE, ARISING
FROM, OUT OF THE USE OR INABILITY TO USE THE FONT SOFTWARE OR FROM
OTHER DEALINGS IN THE FONT SOFTWARE.

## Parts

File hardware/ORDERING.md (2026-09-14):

# Ordering the PocketOBI PCB from PCBWay

You don't need to read a schematic. You just send one `.zip` file, copy a
few settings, and PCBWay makes the board. Plan for about 10 minutes.

## Settings to copy

Board: **91 × 34.5 mm · 2 layers**

| Setting | Value |
|---|---|
| Quantity | 5 (the minimum, cheapest) |
| Layers | 2 |
| Dimensions | 91 × 34.5 mm (auto-detected) |
| Material | FR-4 |
| Thickness | 1.6 mm |
| Surface Finish | HASL (default) |
| Solder mask color | your choice (green = fastest) |
| Silkscreen | white |

Leave everything else on its default value — PCBWay is already set to the
cheapest option.

## Step by step

1. **Get the Gerber file.** It's the manufacturing plan of the board:
   [`gerber/PocketOBI-HW-gerbers-2026-08-05.zip`](gerber/PocketOBI-HW-gerbers-2026-08-05.zip).
   > ⚠️ **Do not unzip it.** PCBWay wants the `.zip` as-is.

2. **Go to PCBWay.** Open <https://pcbway.com/g/EhH6Ny> and click
   **"PCB Instant Quote"** (the big quote button). Stay on the **PCB** tab —
   you don't need assembly.

3. **Upload the .zip.** Click **"+ Add Gerber file"** (or "Quick-order PCB")
   and select the `.zip`. PCBWay reads the file and fills in the **size** and
   **layer count** by itself.
   > 💡 If the detected size is ≈ **91 × 34.5 mm** and **2 layers**, you're
   > good — the right file was loaded.

4. **Check the settings.** Compare against the table above. Set **Quantity**
   to **5**.
   > 💡 Solder mask color and finish are cosmetic/comfort only. Green and HASL
   > are the fastest and cheapest.

5. **Add to cart.** Click **"Save to Cart"**. The price shows up. You'll need
   to **log in or create an account** here (just an email + password).

6. **Address and shipping.** Enter your **address**, then pick the **shipping
   method**. A cheaper carrier = a few more days. Shipping is often half the
   price, so take the time to compare.

7. **Pay.** Card or PayPal. Once paid, the order goes to **review by the
   PCBWay engineers** (a few hours). If they have a question about the file,
   they email you — just confirm.
   > ⚠️ Watch your inbox the first few hours. Production doesn't start until
   > you reply.

8. **Receive your boards.** Manufacturing takes 2-3 days, then it ships. You
   get a **tracking number** by email. All that's left is soldering the
   components. 🔧

## Something went wrong?

Post a screenshot of the step that's stuck in the video comments — we'll
figure it out together.

---

PocketOBI · The Repair Forge — based on the Open Battery Information protocol
(Martin Jansson, MIT).

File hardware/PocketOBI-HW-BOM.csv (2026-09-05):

Refs | Value | Footprint | Qty | DNP
Battery_GND1 | Screw_Terminal_01x02 | TerminalBlock_Phoenix:TerminalBlock_Phoenix_PT-1,5-2-3.5-H_1x02_P3.50mm_Horizontal | 1
Battery_Interface1 | Conn_01x06 | Connector_JST:JST_PH_B6B-PH-K_1x06_P2.00mm_Vertical | 1
M1 | Conn_01x12 | Connector_PinSocket_2.54mm:PinSocket_1x12_P2.54mm_Vertical | 1
R1 | R | Resistor_THT:R_Axial_DIN0207_L6.3mm_D2.5mm_P7.62mm_Horizontal | 1
R2 | R | Resistor_THT:R_Axial_DIN0207_L6.3mm_D2.5mm_P7.62mm_Horizontal | 1
U1 | U1 | ESP32C3-SuperMini:ESP32-C3-SuperMini | 1

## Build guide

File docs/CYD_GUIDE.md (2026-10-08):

# PocketOBI on the CYD — step-by-step guide

This guide takes you from a bare **CYD** board to a working PocketOBI reading a Makita
LXT pack. No prior ESP32 experience is assumed: every step says what to click, what you
should see, and what to do if you don't.

Allow about **45 minutes** the first time (most of it is installing software once).

> The reference PocketOBI is the ESP32-C3 + encoder build ([README](../README.md)). The
> CYD is an alternative board: same firmware, same screens, driven by touch. Pins and
> build switches are summarised in [CYD_NOTES.md](../CYD_NOTES.md).

---

## Contents

1. [What you need](#1-what-you-need)
2. [Check you have the right CYD](#2-check-you-have-the-right-cyd)
3. [Install the software (once)](#3-install-the-software-once)
4. [Get the PocketOBI code](#4-get-the-pocketobi-code)
5. [Build and flash — option A: PlatformIO (recommended)](#5-build-and-flash--option-a-platformio-recommended)
6. [Build and flash — option B: Arduino IDE](#6-build-and-flash--option-b-arduino-ide)
7. [First power-up](#7-first-power-up)
8. [Wire the battery adapter](#8-wire-the-battery-adapter)
9. [Read your first pack](#9-read-your-first-pack)
10. [Using the touch screen](#10-using-the-touch-screen)
11. [Something went wrong](#11-something-went-wrong)

---

## 1. What you need

| Item | Notes |
|---|---|
| **CYD board** "ESP32-2432S028R", **dual-USB revision** (USB-C + micro-USB) | see step 2 |
| USB cable | **data** cable (some charge-only cables have no data wires) |
| Makita **BL1830 LXT adapter** | the plastic shoe that clips onto the 18 V pack |
| **2 × 470 Ω resistors** | pull-ups for DATA and ENABLE (the value the CYD was validated with) |
| A **4-pin JST 1.25 mm cable** for CN1 | usually supplied with the CYD |
| Some wire, a soldering iron (or a small breadboard) | |
| A Windows, macOS or Linux computer | for the one-time flash |
| A multimeter | only if something doesn't read (step 11) |

The back of the board, with the three things this guide refers to:

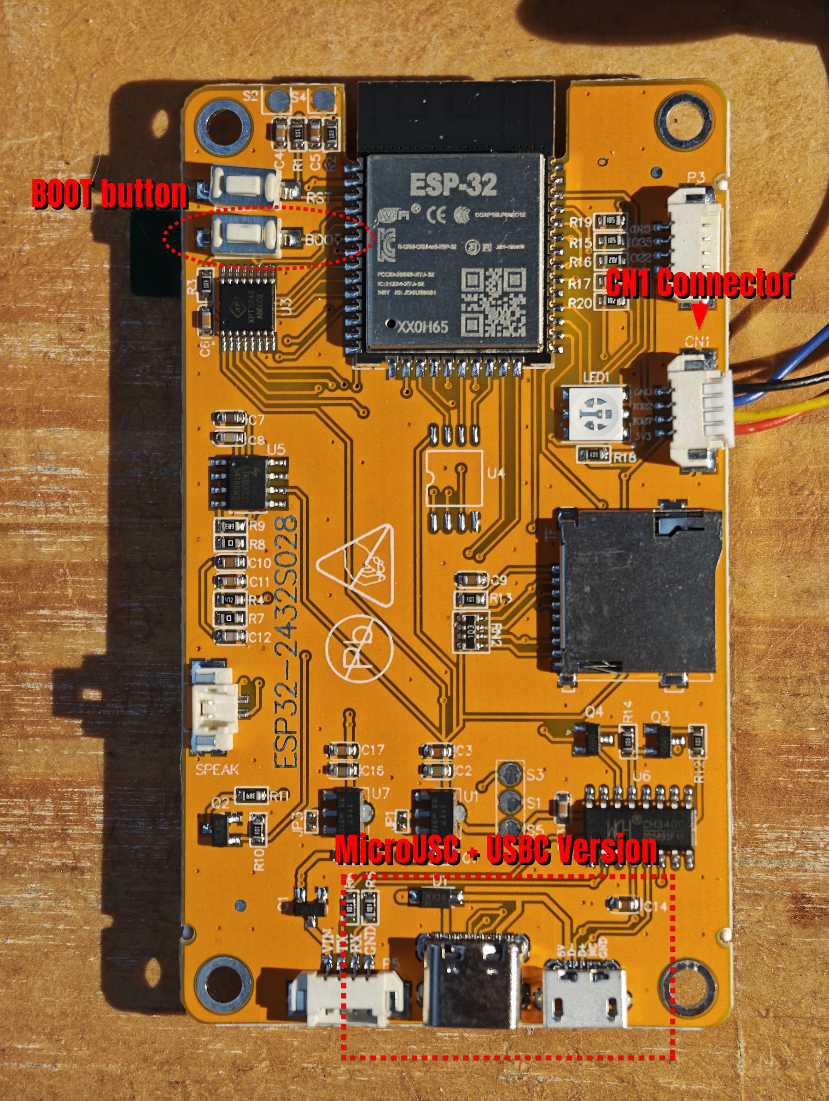
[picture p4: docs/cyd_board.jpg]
Back of the CYD ESP32-2432S028R: BOOT button top left, CN1 connector on the right, USB-C and micro-USB sockets at the bottom
[](cyd_board.jpg)

- **BOOT button**: top left, just below RST. Only needed if flashing fails (step 11).
- **CN1 connector**: right edge, pins marked GND · IO22 · IO27 · 3V3. The battery goes here.
- **USB-C + micro-USB**: bottom edge. Two sockets = the right revision (step 2). Either one works.

---

## 2. Check you have the right CYD

Turn the board over and look at the bottom edge (compare with the photo in step 1):

- ✅ **Two USB sockets (one USB-C, one micro-USB)** → this is the revision PocketOBI
  supports (ST7789 display).
- ⚠️ **A single micro-USB socket** → an older revision with a different display chip.
  It will build and flash, but the screen will stay white or show garbage.

Also find the small white 4-pin connector labelled **CN1**. Its pins are printed next to
it: **GND · IO22 · IO27 · 3V3**. That one connector is all the battery needs.

---

## 3. Install the software (once)

You only do this the first time. Pick **one** of the two toolchains:

- **Option A — PlatformIO** (recommended): it downloads the right libraries and versions
  by itself. You type one command to build and flash.
- **Option B — Arduino IDE**: more familiar if you already use it, but you install the
  libraries by hand.

### 3.1 USB driver (Windows only)

The CYD talks to the PC through a **CH340** USB-serial chip. Windows 10/11 usually
installs the driver automatically. To check:

1. Plug the CYD into the PC.
2. Open **Device Manager** → **Ports (COM & LPT)**.
3. You should see **USB-SERIAL CH340 (COMx)**. Note the `COMx` number.

If you see an unknown device with a yellow triangle instead, install the CH340 driver
from the chip maker (WCH), unplug, plug back in, and check again.

### 3.2 Option A — PlatformIO

1. Install **[Visual Studio Code](https://code.visualstudio.com/)**.
2. In VS Code, open the **Extensions** panel (the four-squares icon on the left), search
   for **PlatformIO IDE**, click **Install**. Wait until it says it is ready (the first
   install takes a few minutes), then restart VS Code.

### 3.3 Option B — Arduino IDE

1. Install **[Arduino IDE 2.x](https://www.arduino.cc/en/software)**.
2. **File → Preferences → Additional boards manager URLs**, paste:
   `https://espressif.github.io/arduino-esp32/package_esp32_index.json`
3. **Tools → Board → Boards Manager**, search **esp32** (by Espressif), install a
   **3.x** version. Avoid versions marked *alpha* or *rc*.
4. **Tools → Manage Libraries**, install each of these:
   - **Adafruit GFX Library**
   - **Adafruit ST7735 and ST7789 Library**
   - **RotaryEncoder** (by Matthias Hertel) — not used on the CYD, but the code expects it
   - **XPT2046_Touchscreen** (by Paul Stoffregen), version **1.4**

   Accept "install all dependencies" when asked.

---

## 4. Get the PocketOBI code

**With git:**

```bash
git clone https://github.com/TheRepairforge/PocketOBI.git
```

**Without git:** on the GitHub page, **Code → Download ZIP**, then unzip it.

> ⚠️ The folder that contains `PocketOBI.ino` **must be named `PocketOBI`**. A ZIP
> download is named `PocketOBI-main`: rename it to `PocketOBI`, otherwise the Arduino IDE
> refuses to open the sketch.

---

## 5. Build and flash — option A: PlatformIO (recommended)

1. In VS Code: **File → Open Folder…** and choose the `PocketOBI` folder.
   PlatformIO notices `platformio.ini` and sets the project up (first time: it downloads
   the ESP32 tools, a few minutes).
2. Open a terminal in VS Code: **Terminal → New Terminal**.
3. Plug the CYD into the PC (either USB socket).
4. Build and flash in one go:

   ```bash
   pio run -e cyd -t upload
   ```

5. You should see the build, then `Connecting....`, a percentage climbing to 100 %, and
   finally **`[SUCCESS]`**. The CYD reboots on its own into PocketOBI.

> Always pass `-e cyd`. Without it, PlatformIO builds and flashes
> **every** board in turn, including the ESP32-C3 build, which will not run on a CYD.

If it stops at `Connecting....` and then fails, see
[step 11 — "Failed to connect"](#failed-to-connect--timed-out-waiting-for-packet-header).

---

## 6. Build and flash — option B: Arduino IDE

1. **File → Open…** and choose `PocketOBI/PocketOBI.ino`. A few tabs open (the sketch and its `.h` files); that's normal.
2. **Tell the code it is running on a CYD.** In the `PocketOBI` folder, create a plain
   text file named exactly **`board_local.h`** containing:

   ```cpp
   #define POCKETOBI_BOARD BOARD_CYD
   ```

   > On Windows, make sure the file is not secretly called `board_local.h.txt`
   > (turn on **View → File name extensions** in Explorer).

   Without this file the IDE builds the ESP32-C3 version, and the CYD screen stays black.
3. **Tools → Board → esp32 → ESP32 Dev Module**.
4. **Tools → Port** → the `COMx` you noted in step 3.1 (`/dev/ttyUSB0` or
   `/dev/cu.wchusbserial…` on Linux/macOS).
5. Leave every other Tools setting at its default.
6. Click **Upload** (the → arrow). The first build takes a few minutes.
7. At the bottom you should see `Writing at … (100 %)` then `Hard resetting via RTS
   pin...`. The CYD reboots into PocketOBI.

---

## 7. First power-up

Right after flashing, still on the PC's USB (no battery yet):

1. The **PocketOBI splash** appears, then the **home screen** with four tiles:
   **Battery · Repair · Tools · About**.
2. **Tap a tile.** If the screen reacts where your finger is, you're done with this step.
3. **If taps land in the wrong place** (or nothing reacts), calibrate the touch panel:
   - Tap **Tools** → **Settings** → **Calibrate touch** (if you can't reach it, see
     [step 11](#taps-land-in-the-wrong-place)).
   - Tap each target firmly, with a fingernail or a stylus, as it appears.
   - "Saved" confirms. The calibration is kept across reboots.
4. **Change the language** if you wish: **Tools → Settings → Language** (each tap moves
   to the next one: EN, FR, DE, ES).
5. **Screen upside-down for your enclosure?** **Tools → Settings → Flip screen**.

From now on the CYD does not need the PC: any **USB phone charger or power bank** powers
it.

---

## 8. Wire the battery adapter

> ⚠️ **The pack's B+ contact is at about 18 V. It must never touch the CYD.** One wrong
> wire and the board is dead. Only three battery contacts are used: **DATA, ENABLE and
> B-**.

### 8.1 Find B+ first, so you can stay away from it

With a multimeter on DC volts: black probe on the big **B-** terminal of the pack, red
probe on each contact in turn. The one that reads **~18–20 V is B+**. Mark it, and leave
it unconnected.

### 8.2 The connections

| CYD (CN1) | Goes to | Notes |
|---|---|---|
| **IO22** | battery **pin 2 — DATA** | + a **470 Ω** resistor from IO22 to 3V3 |
| **IO27** | battery **pin 6 — ENABLE** | + a **470 Ω** resistor from IO27 to 3V3 |
| **GND** | the main **B-** terminal | |
| **3V3** | only the two resistors | nothing else |
| — | battery **pin 1 — B+ (18 V)** | **NEVER CONNECTED** |

The two resistors are the part people forget. Without them the board powers up fine but
never sees the pack. Each one simply bridges a signal wire (IO22, IO27) to the 3V3 wire.

> **Why 470 Ω and not the 4.7 kΩ you may see elsewhere?** 4.7 kΩ is the original
> Open Battery Information value. On the 3.3 V ESP32 the pack pulls the DATA line close
> to the switching threshold, and 4.7 kΩ turned out marginal with ordinary hookup wire;
> 470 Ω reads reliably. ENABLE doesn't need it, it just keeps one resistor value.

```
 CYD  CN1                                   Makita LXT adapter
 ─────────                                  ──────────────────
  3V3 ───┬───────────┐
         │           │
       [470]       [470]
         │           │
 IO22 ───┴───────────┼────────────────────► pin 2   DATA
 IO27 ───────────────┴────────────────────► pin 6   ENABLE
  GND ────────────────────────────────────► B-      (main terminal)
                                            pin 1   B+ 18 V   ✗ never
```

> ⚠️ **Some AliExpress adapters number their contacts from the opposite end.** Do not
> trust the numbers moulded in the plastic: confirm B+ with the multimeter (step 8.1),
> and if the pack does not read, swap the DATA and ENABLE wires before anything else.

**Tip:** cut the 4-pin cable that came with the CYD, solder the two resistors at the
cable end (or on a small piece of perfboard), and keep the joints short and insulated with
heat-shrink.

---

## 9. Read your first pack

1. Power the CYD from USB (PC, charger or power bank).
2. Clip the adapter onto a Makita LXT 18 V pack.
3. Tap **Battery**. PocketOBI reads the pack (a second or two) and shows the overview:
   pack voltage, the five cell voltages, temperature, charge count and a verdict.
4. Tap the **left or right edge** of the screen to move between the three Battery
   pages, the **middle** to read the pack again.

If you get **"No battery found"** or **"Comm error"**, go to [step 11](#11-something-went-wrong).

---

## 10. Using the touch screen

The CYD has no knob and no buttons, so a few gestures replace them:

| To… | Tap… |
|---|---|
| open a tile or a menu item | the tile or the item itself |
| go **back** | the **title bar** (the strip at the top of the screen) |
| change page on **Battery** | the **left or right edge** of the screen (previous / next page) |
| refresh the **Battery** reading | the **middle** of the screen |
| continue on the Repair diagnosis | anywhere below the title bar |
| confirm a write (Repair, Reset error) | anywhere below the title bar — see the warning below |

> ⚠️ **On the two confirmation screens (Repair and Reset error), any tap below the title
> bar confirms and writes to the pack.** To cancel, tap the **title bar**. Keep your
> fingers off the screen while it is showing, and don't rest the board face down on a
> bench.

**What's where:**

- **Battery** — live readings and the verdict for the clipped pack.
- **Repair** — clears a *false* charger lockout on a healthy pack. It writes to the
  battery, so it always asks for confirmation first, and it refuses packs with a real
  fault. Read [Unlock / repair](../README.md#unlock--repair) before using it.
- **Tools** — PC bridge, pack LEDs on/off, reset error, raw debug view, and **Settings**
  (flip screen, PC bridge at boot, language, calibrate touch).
- **About** — version and credits.

**PC bridge:** plug the CYD into a PC, open **Tools → PC bridge**, then connect from the
PackScope desktop app. See [TROUBLESHOOTING.md](../TROUBLESHOOTING.md) if it doesn't connect.

---

## 11. Something went wrong

### Failed to connect / "Timed out waiting for packet header"

The flasher can't put the board into download mode by itself.

1. Start the upload again.
2. As soon as `Connecting....` appears, **press and hold the BOOT button** on the CYD
   (back of the board, top left, just below RST, see the photo in step 1), release it once the percentage starts climbing.
3. Still failing: try the other USB socket, another cable (a data cable), and close
   anything else that might be using the port (Arduino serial monitor, PackScope, Cura…).

### No COM port appears

- Cable is charge-only → try another one.
- Driver missing → step 3.1.

### The screen stays black after flashing

- Arduino IDE: `board_local.h` missing, misnamed (`.h.txt`), or not in the `PocketOBI`
  folder → the C3 build was flashed. Fix it and upload again.
- PlatformIO: you flashed `-e esp32-c3` → flash `-e cyd`.

### The screen stays white or shows garbage

Single micro-USB CYD (older revision, different display chip) → see step 2.

### The image is mirrored (text reads right to left)

Some dual-USB CYDs are fitted with an **ILI9341** display chip instead of the ST7789.
The firmware runs, but the picture is mirrored and the colours are off (the teal title
bar looks olive or khaki green: red and blue are swapped). **Flip screen** won't fix it: it rotates, it
doesn't un-mirror. Build for that panel instead:

- **Arduino IDE:** add this line to your `board_local.h`, then upload again:

  ```cpp
  #define CYD_ILI9341 1
  ```

- **PlatformIO:** `pio run -e cyd-ili9341 -t upload`
- **Prebuilt:** from v2.3.1 the release carries a `cyd-ili9341` binary.

Then run **Tools → Settings → Calibrate touch** once, so taps land where you see them.

### Taps land in the wrong place

Run **Tools → Settings → Calibrate touch**. If you can't hit those items at all, tap
around the bottom-right area of a tile until one opens, then use the title bar to go
back and work your way to Settings. Tap firmly: the panel is resistive and needs a little
pressure, a fingernail works best.

### "No battery found" / "Comm error"

Almost always wiring, not the firmware — flashing again won't change it. In order:

1. Is **B-** really connected to **GND**?
2. Are both **470 Ω pull-ups** fitted (IO22 → 3V3 and IO27 → 3V3)?
3. Are **DATA and ENABLE swapped**? Swap them and try again (see the warning in step 8.2).
4. Is the adapter fully clipped on, contacts clean?

The full multimeter procedure is in **[TROUBLESHOOTING.md](../TROUBLESHOOTING.md)**: it
uses the C3 pin names; on the CYD read **IO22** for DATA and **IO27** for ENABLE.

### See what the board is saying

Plug into the PC and open a serial monitor at **115200 baud**:

```bash
pio device monitor
```

(or the Arduino IDE serial monitor). The boot log and any read error are printed there;
include it if you ask for help.

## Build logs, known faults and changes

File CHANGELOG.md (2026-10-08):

# Changelog

All notable changes to the PocketOBI firmware are documented here.
Versioning follows [Semantic Versioning](https://semver.org/): MAJOR.MINOR.PATCH.

The version is defined in `pocketobi.h` as `FW_VERSION` and shown
on the on-device "Version / info" screen.

## [2.3.1] - 2026-10-08

### Fixed
- **CYD fitted with an ILI9341 panel** (some dual-USB boards, issue
  [#18](https://github.com/TheRepairforge/PocketOBI/issues/18)): the image was mirrored and
  red/blue swapped, because the ST7789 orientation was written to it. New build option
  `CYD_ILI9341` (in `board_local.h`, or the `cyd-ili9341` PlatformIO env) writes the ILI9341
  orientation instead; the release carries a ready `cyd-ili9341` binary. The plain CYD build is
  unchanged. After flashing, run Settings > Calibrate touch once. Thanks to stampeder for the
  reports and the test.
- Two harmless compiler warnings in `OneWire2.cpp` (`#undef` with trailing tokens).

## [2.3.0] - 2026-10-08

Japanese on every screen, a new logo, and the first release with ready-to-flash binaries.

### Added
- **Japanese build** (`ENABLE_CJK=1`; PlatformIO envs `esp32-c3-ja` and `cyd-ja`). Every
  screen is translated except Debug, PC Bridge and About, which stay in English. The text
  is a **first draft no native speaker has reviewed**: corrections are very welcome, see
  `docs/TRANSLATING.md`. Glyphs come from Noto Sans JP Medium (16 px) and Fusion Pixel
  12px ja (12 px), both under the SIL Open Font License (`THIRD-PARTY.md`).
- **The CYD touch-calibration screen is translated** (FR/DE/ES/JA).
- **Screen simulator, `tools/hostsim`**: compiles the real firmware for a PC and saves every
  screen as an image, per language and board, so a translation can be checked without a board.
- **Prebuilt binaries on every release**: one merged image per board (and per language
  build), plus the separate parts and a `SHA256SUMS.txt`. See README, Build & flash.
- **Translation issue form** and a translator guide (`docs/TRANSLATING.md`) covering German,
  Spanish and Japanese.

### Changed (internal, no behaviour change)
- **Firmware source split into modules.** The single `PocketOBI.ino` (~2.6k lines)
  is now a thin sketch (`setup`/`loop` + globals) plus a shared `pocketobi.h` and
  `protocol` / `unlock` / `decode` / `display` / `ui_nav` / `bridge` `.h`/`.cpp`
  modules. Both toolchains build the same root tree unchanged; the flashed firmware
  is functionally identical (same RAM, same behaviour). Pure restructure for
  readability and to give the next protocol family a clean seam.

### Changed
- **New PocketOBI logo** on the splash and About screens: a battery outline split by a
  pulse line, in the Repair Forge orange (replaces the battery-and-bolt mark).

## [2.2.0] - 2026-10-01

Adds a second, alternative carrier board, the **CYD**, with a touch UI. The
ESP32-C3 product is unchanged.

### Added
- **Second carrier board: the CYD (ESP32-2432S028R)** — a development /
  alternative target alongside the shipping ESP32-C3. Same firmware logic,
  different pins and input device, selected at build time. The per-board pin
  map and the board selection live in `board_config.h`.
- **Resistive-touch UI (XPT2046) on the CYD.** The 2×2 launcher, menus and the
  paged Battery view are tap-navigable, with on-device touch calibration
  (Settings > Calibrate) stored in NVS.

### Changed
- **Deterministic multi-board builds.** Each PlatformIO env pins its board with
  `-D POCKETOBI_BOARD`, and the optional (gitignored) local override file is only
  consulted when no board was set explicitly — a build always produces the board
  its env names. The board-selection `#if/#elif` chain lives in `board_config.h`
  (a real header) so the PlatformIO `.ino`→`.cpp` step cannot mangle it.

### Fixed
- Includes the 2.1.1 fix (false "suspect hardware" verdict on healthy BL1850B
  packs), rolled forward from the 2.1 line.

### Note
- The CYD is an alternative board, **bench-validated end to end** (touch UI and
  pack read over the CN1 connector). The ESP32-C3 remains the reference product.
  Wiring and build notes: README (Alternative board: CYD) and `CYD_NOTES.md`.

## [2.1.1] - 2026-09-18

### Fixed
- **False "suspect hardware" verdict on healthy BL1850B packs.** The on-device Debug
  screen showed "Latched: YES" and the verdict read SUSPECT on packs that are balanced,
  unlocked and working, because the low-level BMS marker it relied on turned out
  to be a constant these packs always carry, not a stored fault. The marker no longer
  affects the verdict; a genuinely locked pack is still detected by its charger lock. The
  Debug screen now shows the raw marker bytes for reference. (Reported via issue #13.)

## [2.1.0] - 2026-08-28

First public release since 1.0.0 — the **V2 interface** on a **single-source build**.
(The `2.0.0` line was developed but never published; its work ships here as part of `2.1.0`.)

### Added
- **New V2 interface.** A 2×2 launcher (Battery / Repair / Tools / About), encoder-driven,
  that jumps straight to the Battery view when a pack is connected.
- **Paged Battery view** (turn the encoder): Overview / Health / Identity.
  - *Overview* — per-cell voltage bars (green / yellow / red), pack voltage, cell spread.
  - *Health* — our own cycle-based Condition estimate, over-discharge / over-load wear
    counters, cell min/max + spread, and both temperature sensors + spread.
  - *Identity* — model, charge count, manufacturing date, capacity, and the pack
    **serial number** (ROM ID in Makita 16-char hex format).
- **Traffic-light verdict** — HEALTHY / REPAIRABLE / REAL FAULT, plus an orange
  "possible HW fix" tier — shown on the Battery tile and screens.
- **Repair wizard** — a staged, feasibility-first decision tree: comms check →
  hardware faults (broken sense wire / weak group / imbalance / thermistor, each naming
  the group or sensor) → lock + prognosis (false lockout "should hold" vs a memorised
  fault "unlikely to hold"). A hardware fault blocks the unlock.
- **Multilingual UI** — English, French, German, Spanish.
- **Desk compatibility contract** (PC-bridge opcode `0x02`) reporting a protocol version,
  battery-family id and cell count, so PocketOBI Desk routes to the right decoder and shows
  a non-blocking warning on a version mismatch. The bridge transport stays a stable drop-in
  ArduinoOBI regardless of version.

### Changed
- **Single-source build — the PlatformIO mirror is gone.** A root `platformio.ini`
  (`src_dir = .`) now builds the same files the Arduino IDE compiles, straight from the
  sketch folder; the old `platformio/` mirror project and its `sync.ps1` / `sync.sh` are
  removed. `PocketOBI.ino` stays at the repo root, so the Arduino IDE build is unchanged —
  one set of sources, both toolchains, nothing to keep in sync.
- **Thermistor finding is now evidence-based**, an observation plus a suggested re-check
  rather than a bare "replace the sensor"; a sensor-spread divergence is a soft "possible
  HW fix" that does **not** block the unlock.
- **One verdict everywhere.** The Repair wizard banner shows the exact same verdict —
  word, colour and icon — as the Battery tile, computed from a single source.
- **The undecoded raw "status" byte no longer drives any decision.** The error-reset
  result now tracks the real BMS fault register (LOCKED → OK = "cleared", still LOCKED =
  "unchanged", nothing set = "no error to clear"); the raw byte is shown only on the Debug
  screen, marked undecoded.
- **Repair prognosis reads as guidance, not a guarantee** — a memorised-fault marker is a
  hint ("unlikely to hold"), never a hard verdict, and never blocks an unlock attempt.

### Fixed
- **PC bridge hardening** — serial buffers are bounded against oversized `len` / `rsp_len`,
  and truncated frames are dropped instead of half-executed (the PC app simply resends).
- **Removed the dead V1 menu/screen cluster** (~225 lines) left unreachable under V2
  navigation.
- **PC-bridge interface version derives from the firmware version** (was hardcoded/stale).

### Notes
- The public version jumps **`v1.0.0 → v2.1.0`**; `2.0.0` was internal-only.
- Licence: PolyForm Noncommercial 1.0.0 (unchanged from 1.0.0). Upstream Open Battery
  Information and the bundled OneWire2 remain MIT — see `THIRD-PARTY.md`.

## [1.0.0] - 2026-08-05

First official, stable release. The core decodes (protocol, temperature, cell
voltages, capacity, charge count) are cross-validated on real packs. A larger V2
(more readouts + UI overhaul) is planned separately.

### Changed
- **Faulty-thermistor reading now flagged explicitly.** When a temperature sensor
  reads outside the plausible window it is shown with a leading `!` in red on the
  home chip (e.g. `!-30/31`) = suspected **faulty sensor / hardware fault**, not a
  real extreme temperature. (A dead thermistor pins near -30 C.)

### Validated
- **Temperature unit (1/10 K) validated on real packs.** Readings from several packs
  (including one with a known faulty thermistor) confirm `T_C = raw/10 - 273.15`, and
  that a dead thermistor reads a pinned absurd value (~ -30 C) — exactly the behaviour
  PocketOBI already flags. No decode change needed; the comments now record it.

## [0.9.7] - 2026-08-04

### Added
- **Details screen: state-of-health estimate + protection thresholds.** The
  standard-battery Details view now shows `Health~` (a cycle-based SoH *estimate*,
  the `~` marking it as an estimate rather than the BMS's own gauge) and
  `Prot OL/OD` (over-current / over-discharge protection thresholds, in %). All
  three are decoded from the ROM message frame already read — **no extra bus
  traffic**. The decodes are corroborated by both sides of the
  [m5din-makita](https://github.com/no-body-in-particular/m5din-makita) fork (its
  reader and its BMS emulator store/read the same bytes the same way). Values are
  best-effort: the absolute figures are not yet confirmed against a bench meter.
- **Dual capacity-format decode.** Battery capacity (frame byte 16) is now decoded
  for both encodings: newer packs store it directly in whole Ah, older packs store
  a nibble-swapped value in tenths of an Ah. (From the MIT-licensed
  [drakosha/makita-battery-tools](https://github.com/drakosha/makita-battery-tools).)

### Documented
- **Secondary frame checksums (CS3/CS4 in byte 31).** Added an in-code note on the
  two secondary checksums (byte 31: covers bytes 22-23 and 24-30, the latter
  including overload / over-discharge / cycle-count). No behaviour change - the
  unlock only touches the CS2 range - but any future write to bytes 22-30 must
  recompute byte 31. Corroborated by drakosha/makita-battery-tools, whose decode of
  the three primary checksums matches ours exactly.

### Changed
- Temperature-unit note (README + code comment) upgraded from "disputed" to
  "well-supported": the 1/10 K decode is now corroborated by four independent
  sources (rosvall, obi-esp32, and both the reader and BMS emulator of the
  m5din-makita fork). Open Battery Information's Celsius×100 is the outlier.

## [0.9.6] - 2026-08-02

### Added
- **PlatformIO build** (`platformio/`): a conventional PlatformIO project
  (src/ + lib/) for VS Code users, alongside the Arduino IDE build. It mirrors
  the root Arduino sources via `platformio/sync.ps1` / `sync.sh`; the root
  `PocketOBI.ino` remains the single source of truth. (Addresses issue #1.)

## [0.9.5] - 2026-08-02

### Changed
- The home temperature chip now shows **both sensors** (cell / MOSFET, e.g.
  `28/31`) instead of only the cell reading, so a disagreement between the two is
  visible at a glance. It turns red when either reading is outside the plausible
  window (likely faulty thermistor). F0513 (single sensor) is unchanged.
- README/HARDWARE wording tidied for the public release; the unlock/repair is
  described by its scope (clears a false charger lockout on an otherwise-healthy
  pack; never overrides the BMS's own fault protection).

## [0.9.4] - 2026-07-30

### Fixed / hardened (pre-release audit against all protocol sources)
- **PC bridge** now reports the real firmware version in the interface-version
  query (was hardcoded to 0.8.x).
- **F0513**: clear `romId`/`msg` on the F0513 path so Debug/raw no longer shows
  stale data left over from a previously-read standard pack.
- **10-cell / 36V packs (BL36xx)**: detected (battery type >= 30) and shown as
  "not supported (18V only)" instead of a misleading 5-cell dashboard.
- **Robustness**: guard against a `uint8_t` underflow if a `0x33` command were
  ever defined with `rsp_len < 8`.
- Added a note that the **F0513 temperature unit is unverified** (kept at /100;
  the standard path uses 1/10 K).

## [0.9.3] - 2026-07-30

### Added
- Implausible-temperature flag: when the cell temperature falls outside a
  plausible window (`TEMP_MIN_PLAUS`..`TEMP_MAX_PLAUS`, -20..80 C), the home
  temperature chip turns red and shows a trailing `?` (e.g. `T -30?`) — a
  likely faulty thermistor. It is a suspicion, not a confirmed diagnosis.

## [0.9.2] - 2026-07-30

### Fixed
- **Temperature decoding**: the protocol reports temperature in **1/10 K**
  (`raw = (T_C + 273.15) * 10`), not Celsius x100. Cell and MOSFET temperatures
  are now decoded as `raw / 10 - 273.15`. Previous values were a few degrees off
  on a healthy pack, and — more importantly — a **faulty thermistor** (which
  reports an absurd value the charger rejects as a "temperature" fault) now shows
  its true reading (e.g. ~ -30 C) instead of a misleading normal-looking number.

## [0.9.1] - 2026-07-29

### Added
- Serial trace of the raw frame write/store (`ow33`) under `COMM_DEBUG`, so the
  otherwise-invisible unlock writes show up in the logs.

### Fixed
- Home + Details **LOCKED/UNLOCKED** now reflects the real **charger lock**
  (nybble 34 / CS0 / CS2 mismatch, i.e. what actually makes the charger refuse a
  pack), not only the failure code (nybble 40). Details also shows a `ChgLock:`
  line listing the causes (`N34`/`CS0`/`CS1`/`CS2`). Previously a frame whose
  charger-lock nybble was set could still read UNLOCKED on screen.

## [0.9.0] - 2026-07-26

### Added
- **Unlock / repair** menu entry: rewrites a battery frame to make the charger
  accept a pack whose cells are healthy but whose stored frame trips the charger
  lock. Clears the charger-lock nybble (nybble 34) and recomputes all three
  frame checksums (CS0, CS1, CS2 - CS0/CS2 gate the charger, CS1 the battery's
  internal lock), then writes the frame back
  (arm `CC F0 00` -> write `33 0F 00` + 32 bytes -> store `33 55 A5`), power-
  cycles the bus and clears the internal error register. Guarded by a
  confirmation screen; if the frame is already valid, no write is performed.
  Shows the lock causes before -> after. Manufacturing/status bytes (incl.
  byte 19 / `0xA5`) and the failure code (nybble 40) are never modified.
- Result screen reporting the remaining lock causes (`CS0`/`CS1`/`CS2`/`N34`) and
  an Unlocked / Still-locked verdict.

### Changed
- **Error reset** now runs the full sequence: enter test mode -> `DA 04` ->
  exit test mode (`CC D9 FF FF`) -> bus power-cycle, so the BMS actually commits
  the internal error-register clear (previously it stopped after `DA 04`).

### Notes / credit
- The unlock/frame-repair capability is a **clean-room** reimplementation from
  publicly documented protocol facts (frame byte/nybble map, checksum ranges +
  formula, nybble-34 charger lock, arm/write/store opcodes). Sources:
  - **rosvall/makita-lxt-protocol** (Codeberg) — root reverse-engineering of the
    frame layout and the three checksum ranges (0-15, 16-31, 32-40).
  - **synrais/Makita-LXT-Battery-Monitor-Unlocker** — frame-repair method and the
    empirical charger-validation results (only nybble 34, CS0, CS2 gate the
    charger). This repo ships with **no license** (all rights reserved), so none
    of its source code is used — only the unprotectable protocol facts, cross-
    checked against real battery dumps.
  - Base protocol credit remains Open Battery Information (Martin Jansson, MIT).

## [0.8.1] - 2026-07-21

### Changed
- Clearer lock status: home footer shows **UNLOCKED** (green) / **LOCKED** (red)
  instead of "OK". Added an explicit colored "State: UNLOCKED/LOCKED" line to the
  Details screen.

## [0.8.0] - 2026-07-21

### Added
- **PC bridge mode** (menu entry "PC bridge"): the device acts as a USB <->
  OneWire bridge, a drop-in replacement for the ArduinoOBI, so the desktop
  **Open Battery Information** app talks to PocketOBI directly (select the
  Arduino OBI interface + PocketOBI's COM port). Handles the version query and
  the 0xCC / 0x33 / F0513 (0x31,0x32) commands via the existing sendCommand().
  Back button exits. Dual use: standalone tester AND PC adapter.

### Changed
- COMM_DEBUG serial tracing defaults to OFF (comms validated). It MUST stay off
  in PC bridge mode or it would corrupt the binary protocol.

## [0.7.0] - 2026-07-21

### Added
- Estimated state of charge (SoC ~%) on the home screen, derived from the
  average cell voltage (piecewise-linear Li-ion OCV curve; approximate, shown
  with a "~").

### Changed
- Boot now goes: splash (~1.5 s) -> menu directly. No auto-read and no
  "no battery" home screen; the user picks what to do from the menu.

## [0.6.2] - 2026-07-21

### Changed
- Removed the auto-read at boot. The boot splash now shows for ~1.5 s as a
  simple logo screen, then the home screen appears; the user starts a read from
  the menu. (First real-hardware validation: reads a BL1860B correctly.)

## [0.6.1] - 2026-07-21

### Changed
- Ground is now taken from the main B- terminal (simpler and more reliable than
  signal pin 5; same ground). Wiring docs updated accordingly.
- "beta" tag shown on the splash and About screens; README gains a "Step 1
  (beta)" status section and a link to The Repair Forge YouTube channel.

## [0.6.0] - 2026-07-21

### Changed
- Tool named **PocketOBI** (standalone OBI client). Boot splash now shows the
  name in big two-tone letters ("Pocket" teal + "OBI" orange) instead of the
  logo. About screen features PocketOBI, credits "The Repair Forge" as creator,
  and keeps the base-project credit (Open Battery Information, Martin Jansson).

### Removed
- Primitive-drawn logo mark (anvil/wrench/spark) dropped in favor of the name.

## [0.5.0] - 2026-07-21

### Added
- Credit to the base project on the About screen: Open Battery Information by
  Martin Jansson (MIT), github.com/mnh-jansson.

## [0.4.0] - 2026-07-21

### Added
- Boot splash screen (title + version + "Reading battery...").
- Auto-read on startup: the tool attempts a battery read at boot, so the home
  screen shows real data immediately when a pack is present instead of always
  claiming "no battery" before ever checking.

### Changed
- Home "no battery" screen now only appears after an actual read attempt, with
  a clearer prompt ("Connect a pack, then Menu > Read battery").

## [0.3.2] - 2026-07-21

### Fixed
- Battery communication never started: the code aborted every transaction on
  `makita.reset()` returning 0. The Makita BMS does not assert a standard
  OneWire presence pulse, so the official ArduinoOBI ignores that return value.
  We now reset and talk regardless, and detect "no battery" from an all-0xFF
  response instead.

### Added
- COMM_DEBUG serial trace of every OneWire transaction (presence flag, ROM ID,
  received bytes) to diagnose battery communication on real hardware.

## [0.3.1] - 2026-07-21

### Fixed
- Encoder rotation direction was reversed; swapped A/B in the RotaryEncoder
  constructor so turning right moves down the menu.

## [0.3.0] - 2026-07-21

### Added
- Secondary "back" button support on the module's KO button (wire KO to GPIO2):
  short press = go one screen back (sub-screen -> menu, menu -> home),
  long press (>= 600 ms) = jump straight to home. Uses the internal pull-up,
  so it stays inert until KO is actually wired.

## [0.2.0] - 2026-07-20

### Changed
- Menu bullets replaced with real icons drawn from primitives (battery, list,
  refresh, sun, sun-off, code, info). On the highlighted row the icon is forced
  to the light header color so it stays visible on the accent background.

## [0.1.0] - 2026-07-20

First versioned release. The firmware is feature-complete on the UI side but
the battery OneWire2 communication has not yet been validated against real
hardware (waiting for the battery connector).

### Added
- Standalone Makita LXT reader on ESP32-C3 + ST7789 2.4" TFT + EC11 encoder.
- OneWire2 protocol layer (bundled), commands ported from `makita_lxt.py`.
- Automatic standard / F0513 battery detection.
- Home screen with per-cell voltage bars, color-coded anomalies
  (green / yellow / red) and status chips (temperature, spread, lock/error).
- Menu: read info, details, reset error, pack LEDs on/off, debug/raw,
  version/info.
- Error reset with before -> after visual feedback.
- Dark dashboard theme: accent header bars, rounded bars, colored menu bullets.
- "Version / info" screen showing firmware version and build date.

### Hardware / libraries
- Display driven with Adafruit GFX + Adafruit ST7789 over hardware SPI.
- Encoder decoded with the RotaryEncoder library (software, ESP32-C3 compatible).

### Known / untested
- OneWire2 battery communication never tested on real hardware.
- Display orientation is landscape (`setRotation(1)`); portrait not done yet.

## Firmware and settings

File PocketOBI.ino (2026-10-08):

// SPDX-License-Identifier: PolyForm-Noncommercial-1.0.0
// Copyright (c) 2026 TheRepairForge
/*
 * PocketOBI - Standalone Makita LXT battery reader / diagnostic
 * ESP32-C3 SuperMini + SPI TFT display + EC11 rotary encoder
 *
 * Required libraries:
 *  - OneWire2: bundled directly in this folder (OneWire2.h/.cpp + util/).
 *    This is the modified library from the open-battery-information project,
 *    with bit-level timings that differ from the standard OneWire library:
 *      reset      : 750 us (vs 480 us standard)
 *      write-1 slot: ~132 us (vs ~65 us)
 *      write-0 slot: ~130 us (vs ~70 us)
 *      read pulse  : 10 us  (vs 3 us)
 *    These deviations are intentional: the Makita BMS does not respond with
 *    standard Maxim OneWire timings.
 *  - Adafruit GFX Library + Adafruit ST7735 and ST7789 Library
 *    (Arduino IDE Library Manager). Display config is 100% in this file
 *    (pins + driver); no external User_Setup.h to edit. Hardware SPI.
 *  - RotaryEncoder (Matthias Hertel): software encoder decoding, compatible
 *    with the ESP32-C3 (which has no hardware pulse-counter peripheral).
 *
 * Battery protocol wiring (reference: appositeit/obi-esp32 project):
 *  GPIO3  -> Battery pin 2 (DATA, OneWire)   + 470 ohm pull-up to 3.3V
 *  GPIO4  -> Battery pin 6 (ENABLE)          + 470 ohm pull-up to 3.3V
 *  (470 ohm on both: DATA needs the strong pull-up for the 3.3V input
 *   threshold; ENABLE is driven, so same value for a single-value BOM)
 *  GND    -> Battery B- (main negative terminal; simpler and more reliable
 *            than signal pin 5, they share the same ground)
 *  NEVER connect B+ (18V) to the ESP32.
 *
 * TFT SPI display wiring (configured directly in this file):
 *  GPIO0  -> SCL/SCK
 *  GPIO1  -> SDA/MOSI
 *  GPIO10 -> RES
 *  GPIO20 -> DC
 *  GPIO21 -> CS
 *  3.3V   -> VCC + BLK
 *
 * EC11 encoder wiring:
 *  GPIO5  -> A
 *  GPIO6  -> B
 *  GPIO7  -> PUSH (built-in button, to GND, internal pull-up)
 *  GPIO2  -> KO   (module secondary button; short = back, long = home).
 *                 GPIO2 is a strapping pin: do not hold KO while powering on.
 *
 * PROTOCOL:
 * Commands taken verbatim from the official source file
 * OpenBatteryInformation/modules/makita_lxt.py (MIT project, Martin Jansson).
 * Command layout [0x01, len, rsp_len, cmd, data...], identical to the
 * ArduinoOBI USB protocol:
 *  - cmd 0xCC: reset, write 0xCC, write `len` data bytes, read rsp_len
 *  - cmd 0x33: reset, write 0x33, read 8 ROM ID bytes, write `len` data bytes,
 *              read (rsp_len - 8) remaining bytes (rsp_len includes the 8 ROM ID)
 *
 * UNLOCK / FRAME REPAIR (v0.9.0):
 * The write-back / charger-unlock capability (writeFrame(), the CS0/CS2 checksum
 * math, the nybble-34 charger-lock and the arm/write/store opcodes) is a
 * CLEAN-ROOM reimplementation from the publicly documented protocol facts of the
 * synrais/Makita-LXT-Battery-Monitor-Unlocker project. That repository ships
 * with NO license (all rights reserved), so NONE of its source code is copied
 * here; only the unprotectable protocol facts (opcodes, checksum formula, byte
 * map) are reused, cross-checked against real battery dumps. Credit to synrais
 * for the frame-repair research, to the rosvall/makita-lxt-protocol project for
 * the root protocol reverse-engineering (frame byte map, checksum ranges), and
 * to Open Battery Information (Martin Jansson, MIT) for the base protocol.
 * See README.md and CHANGELOG.md.
 *
 * Charger acceptance depends on exactly three frame fields (empirically
 * established by synrais over 200+ tests): nybble 34 (byte 17 low = charger
 * lock, must be 0), CS0 (nybble 41 = sum(nybbles 0-15) & 0x0F) and CS2
 * (nybble 43 = sum(nybbles 32-40) & 0x0F). Byte 19 (status, e.g. 0xA5) and the
 * cell temperatures are NOT part of the charger's frame check.
 */


#include "pocketobi.h"
#include "protocol.h"
#include "unlock.h"
#include "decode.h"
#include "display.h"
#include "ui_nav.h"
#include "bridge.h"
#include "strings_ja.h"   // STRTAB_JA, only when ENABLE_CJK=1


OneWire makita(ONEWIRE_PIN);
// Hardware-SPI constructor (much faster than software SPI): (&SPI, cs, dc, rst).
// SCLK/MOSI pins are assigned via SPI.begin() in setup().
PocketTFT tft(&SPI, TFT_CS, TFT_DC, TFT_RST);   // = Adafruit_ST7789, UTF-8 aware in the JA build

#if BOARD_HAS_TOUCH
// The display drives the default SPI object (remapped to its HSPI pins in setup()),
// so the XPT2046 touch controller gets its OWN bus on a second SPIClass.
#include <XPT2046_Touchscreen.h>
SPIClass touchSPI(HSPI);
XPT2046_Touchscreen touch(TOUCH_CS, TOUCH_IRQ);

// Resistive-touch calibration: raw XPT2046 -> screen pixels. On this CYD the axes
// are crossed (screen X from the raw Y axis inverted, screen Y from the raw X axis);
// map() handles the inverted ranges. The four corner values live in NVS and are
// editable from Settings > Calibrate; these #defines are the factory fallback,
// measured on the bench. Re-run Calibrate after a panel swap.
int tcXL = TCAL_DEF_X_LEFT, tcXR = TCAL_DEF_X_RIGHT,
    tcYT = TCAL_DEF_Y_TOP,  tcYB = TCAL_DEF_Y_BOTTOM;
// Set to 1 to calibrate manually: each tap draws a dot where it maps + prints
// raw/mapped coords and does NOT navigate. Set back to 0 when tuned.
// Edge-detect state: act once per touch, on touch-down (not while held).
bool touchDown = false;
unsigned long lastTouchMs = 0;
#endif






UiState state = LAUNCHER;
int lastRenderedState = -1; // so the screen is only cleared when the screen changes

// ---------- V2 navigation indices ----------
int launcherIndex = 0;   // 0=Battery 1=Repair 2=Tools 3=About
int batteryPage   = 0;   // 0=Overview 1=Health 2=Identity
int toolIndex     = 0;
// About easter egg: rotate the encoder on the About screen. 0 = off; each detent
// advances one retro one-liner; one turn past the last line = the mock Guru crash.
int  aboutEgg = 0;
bool aboutCrashDrawn = false;

// ---------- i18n: string table lives in strings_i18n.h (data only). The tr()
// accessor and the mutable `lang` selector are logic/state and stay here. ----------
int lang = LANG_EN;
const char* tr(StrId id) {   // prototype in pocketobi.h
#if ENABLE_CJK
  if (lang == LANG_JA) return STRTAB_JA[id] ? STRTAB_JA[id] : STRTAB[id][LANG_EN];
#endif
  return STRTAB[id][lang];
}

const int   toolCount = 6;
#if BOARD_HAS_TOUCH
const int   settingsCount = 4;   // Flip screen, PC bridge at boot, Language, Calibrate touch
#else
const int   settingsCount = 3;   // Flip screen, PC bridge at boot, Language
#endif

// ---------- Settings (persisted in NVS) ----------
Preferences prefs;
bool cfgFlip = false;        // rotate the screen 180 deg
bool cfgBridgeBoot = false;  // boot straight into PC bridge
int  settingsIndex = 0;
int _ry = 0;             // shared vertical cursor for key/value rows


// Reset visual feedback. The error-reset (TESTMODE + RESET_ERROR) targets the BMS
// FAULT register = bat.locked (msg byte-20 low nibble / nybble 40), so the before ->
// after tracks THAT, not the undecoded status byte 19. See the byte-19 note on the
// errorCode field: byte 19 is checksum-covered but carries no interpreted meaning in
// any known tool -> it is not a verdict input.
bool resetLockedBefore = false;
bool resetLockedAfter = false;

// Unlock/repair feedback: charger-lock causes before -> after (bitmask, see LF_*).
uint8_t unlockCausesBefore = 0;
uint8_t unlockCausesAfter = 0;

// ---------- Encoder ----------
// Software decoding via RotaryEncoder (Matthias Hertel). Robust state machine:
// LatchMode::FOUR3 = rests at a detent when A and B are both high (typical EC11),
// 1 mechanical detent = 1 position step, direction handled correctly.
// Polled from loop() (tick()) to avoid any interrupt/IRAM concern.
RotaryEncoder *encoder = nullptr;
long lastEncPos = 0;
bool btnPressed = false;
unsigned long lastBtnTime = 0;

// Secondary "back" button state (short press = back, long press = home).
bool backDown = false;
bool backLongFired = false;
unsigned long backStart = 0;







BatteryData bat;

// ---------- Makita OneWire low level ----------
// Inter-byte timing taken from the official ArduinoOBI firmware (main.cpp):
// 90 us between each byte written or read, 400 us after each reset.
// The intra-bit timing (slots) is handled by OneWire2 itself.
// ENABLE_PIN is driven HIGH + 400 ms wait before every transaction.















































// PC bridge mode: the tool acts as a USB<->OneWire bridge for the Open Battery
// Information PC app (drop-in ArduinoOBI replacement). Serial debug is suppressed
// while in this state (it would corrupt the binary protocol).
// PC bridge running state; the encoder toggles it live on the PC bridge screen.
bool bridgeActive = true;



// ================= V2 UI ==================
// (enum Verdict is defined near the top, with the other enums.)

int lastBatteryPage = -1;  // force a screen clear when the Battery page changes







































// ---------- Setup / loop ----------
void setup() {
  Serial.begin(115200);

  pinMode(ENABLE_PIN, OUTPUT);
  digitalWrite(ENABLE_PIN, LOW);

#if BOARD_HAS_ENCODER
  pinMode(ENC_BTN, INPUT_PULLUP);
  pinMode(BACK_BTN, INPUT_PULLUP);

  // Encoder: the library enables the internal pull-ups. Read by polling
  // (tick() called in the loop): simple and free of interrupt concerns.
  // A/B swapped on purpose so the rotation direction matches the display.
  encoder = new RotaryEncoder(ENC_B, ENC_A, RotaryEncoder::LatchMode::FOUR3);
#endif

#if BOARD_HAS_TOUCH
  // XPT2046 on its own SPI bus; we read raw points and map them ourselves.
  touchSPI.begin(TOUCH_CLK, TOUCH_MISO, TOUCH_MOSI, TOUCH_CS);
  touch.begin(touchSPI);
  touch.setRotation(0);
#endif

#ifdef TFT_BL
  // CYD: the backlight is GPIO-controlled — without this the panel stays black.
  pinMode(TFT_BL, OUTPUT);
  digitalWrite(TFT_BL, HIGH);
#endif

  // Hardware SPI on the board's pins (see BOARD HEADER). Must be called before
  // tft.init(): this "claims" the bus with the correct pins.
  SPI.begin(TFT_SCLK, -1, TFT_MOSI, TFT_CS);

  // Load persisted settings before configuring the display.
  prefs.begin("pocketobi", false);
  cfgFlip       = prefs.getBool("flip", false);
  cfgBridgeBoot = prefs.getBool("bridge", false);
  lang          = prefs.getInt("lang", LANG_EN);
  if (lang < 0 || lang >= LANG_NUM) lang = LANG_EN;   // e.g. JA saved, then a non-JA build flashed
#if BOARD_HAS_TOUCH
  tcXL = prefs.getInt("tcXL", TCAL_DEF_X_LEFT);
  tcXR = prefs.getInt("tcXR", TCAL_DEF_X_RIGHT);
  tcYT = prefs.getInt("tcYT", TCAL_DEF_Y_TOP);
  tcYB = prefs.getInt("tcYB", TCAL_DEF_Y_BOTTOM);
#endif

  tft.init(240, 320);        // 240x320 ST7789 panel (both boards)
  tft.invertDisplay(false);  // correct colors on both boards' ST7789 panels
  applyRotation();

  // Boot splash, then straight to the launcher (or the PC bridge if configured). We deliberately
  // do NOT auto-read the pack at boot: a full read is ~seconds (the ENABLE wake dominates), which
  // made startup feel slow. The read is on demand — launcher item 0 (Battery) / 1 (Repair) trigger
  // it. Insert pack, boot lands on the launcher instantly, click to read.
  drawSplash();
  delay(1500);
  state = cfgBridgeBoot ? PC_BRIDGE : LAUNCHER;
  render();
}

void loop() {
#if BOARD_HAS_ENCODER
  // Encoder polling: to be called as often as possible.
  encoder->tick();
#endif

  // PC bridge mode: act as a USB<->OneWire bridge for the PC app (only while active).
  if (state == PC_BRIDGE && bridgeActive) serviceBridge();

#if BOARD_HAS_ENCODER
#if ENC_DEBUG
  // Trace raw pin transitions + the library position over serial.
  static int lastRawA = -1, lastRawB = -1;
  int ra = digitalRead(ENC_A), rb = digitalRead(ENC_B);
  if (ra != lastRawA || rb != lastRawB) {
    lastRawA = ra; lastRawB = rb;
    Serial.printf("A=%d B=%d pos=%ld\n", ra, rb, encoder->getPosition());
  }
#endif

  // Encoder rotation: the position (in detents) is maintained by the library.
  // Apply the difference since the last read.
  long pos = encoder->getPosition();
  long diff = pos - lastEncPos;
  lastEncPos = pos;
  int steps = abs(diff);
  for (int i = 0; i < steps; i++) {
    handleRotate(diff > 0 ? 1 : -1);
  }

  // Encoder button (simple debounce, acts on press)
  bool pressed = (digitalRead(ENC_BTN) == LOW);
  if (pressed && !btnPressed && millis() - lastBtnTime > 250) {
    btnPressed = true;
    lastBtnTime = millis();
    handleClick();
  } else if (!pressed) {
    btnPressed = false;
  }

  // Back button: short press (on release) = back, long press = home.
  bool backNow = (digitalRead(BACK_BTN) == LOW);
  if (backNow && !backDown && millis() - backStart > 50) {
    backDown = true;
    backStart = millis();
    backLongFired = false;
  } else if (backNow && backDown && !backLongFired &&
             millis() - backStart >= BACK_LONG_MS) {
    backLongFired = true;  // long press reached -> home immediately, fire once
    goHome();
  } else if (!backNow && backDown) {
    backDown = false;
    if (!backLongFired) handleBack();  // released before the long threshold
  }
#endif // BOARD_HAS_ENCODER

#if BOARD_HAS_TOUCH
  serviceTouch();   // read the XPT2046, hit-test the screen, drive the nav core
#endif

  delay(1);
}

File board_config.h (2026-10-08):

#pragma once
// Board selection + per-board pin map. This lives in a real header ON PURPOSE:
// PlatformIO's .ino->.cpp converter relocates #define directives, which breaks the
// exclusivity of an #if/#elif pin-selection chain when it sits inside the .ino (both
// board blocks end up compiled, last-wins -> wrong pinout). A .h is included verbatim
// by both PlatformIO and the Arduino IDE, so the chain stays exclusive. Keep the
// board pin map here; the sketch only consumes the resulting macros.

// ================= BOARD SELECTION =================
// PocketOBI runs on more than one carrier board. Exactly one is selected here,
// as a plain #define so "open PocketOBI.ino in the Arduino IDE and flash" works
// with no external build config; a PlatformIO/CI build can override it with
// -DPOCKETOBI_BOARD=BOARD_xxx. A board differs only in the BOARD HEADER below
// (pins) and in which input device it carries (capability flags) — never in the
// logic. This is the XGT seam of REPO_MAP.md, generalised to a second board.
#define BOARD_LXT_C3 1   // ESP32-C3 SuperMini + ST7789 + EC11 encoder (shipping product)
#define BOARD_CYD    2   // "Cheap Yellow Display" ESP32-2432S028R: ST7789 + XPT2046 touch (dev/alt)

// Optional LOCAL board override (gitignored, never committed): drop a file
// "board_local.h" next to this header containing e.g.
//     #define POCKETOBI_BOARD BOARD_CYD
// to build for a non-default board WITHOUT editing this tracked file.
// An explicit build flag (-DPOCKETOBI_BOARD=... from a PlatformIO env or CI)
// takes precedence: board_local.h is only consulted when nothing defined it
// yet, so a per-env build is deterministic even on a machine that carries a
// board_local.h. The Arduino IDE (no build flag) still honours the file.
#if !defined(POCKETOBI_BOARD) && defined(__has_include)
#  if __has_include("board_local.h")
#    include "board_local.h"
#  endif
#endif

#if !defined(POCKETOBI_BOARD)
#  define POCKETOBI_BOARD BOARD_LXT_C3   // default = the shipping product; override via board_local.h
#endif

// Capability flags — test the CAPABILITY, not the board id, in the logic below,
// so a future third board reuses the same #if without editing every call site.
#define BOARD_HAS_ENCODER (POCKETOBI_BOARD == BOARD_LXT_C3)
#define BOARD_HAS_TOUCH   (POCKETOBI_BOARD == BOARD_CYD)

// ================= BOARD HEADER =================
// Every GPIO assignment lives here, nowhere else. A new board adds one branch.
// Three sub-blocks per board: battery bus / input device / display.
#if POCKETOBI_BOARD == BOARD_LXT_C3
// --- PocketOBI-LXT (ESP32-C3 SuperMini) — the shipping product ---
// --- Battery bus ---
#define ONEWIRE_PIN 3
#define ENABLE_PIN  4
// --- Input: rotary encoder (EC11) + secondary "back" button ---
#define ENC_A    5
#define ENC_B    6
#define ENC_BTN  7
#define BACK_BTN 2   // module "KO" secondary button: short = back, long = home
// --- Display: ST7789 TFT (SPI) ---
#define TFT_CS   21
#define TFT_DC   20
#define TFT_RST  10
#define TFT_MOSI 1   // SDA
#define TFT_SCLK 0   // SCL

#elif POCKETOBI_BOARD == BOARD_CYD
// --- CYD ESP32-2432S028R, dual-USB (USB-C + micro) revision (dev/alt target) ---
// Confirmed from this board's silkscreen: CN1 = {GND, IO22, IO27, 3V3}, and IO27
// being broken out means the backlight is on GPIO21 (not 27) -> both 22 and 27 are
// free. CN1 is therefore the whole pack connector on one 4-pin header:
//   GND | DATA(22) | ENABLE(27) | 3V3 (for the two 4.7k pull-ups)
// --- Battery bus (CN1) ---
#define ONEWIRE_PIN 22   // CN1 IO22, + 4.7k pull-up to 3V3
#define ENABLE_PIN  27   // CN1 IO27, + 4.7k pull-up to 3V3
// --- Input: resistive touch (XPT2046, its OWN SPI bus). No encoder, no back button. ---
#define TOUCH_CLK  25
#define TOUCH_MOSI 32
#define TOUCH_MISO 39
#define TOUCH_CS   33
#define TOUCH_IRQ  36
// --- Display: ST7789 TFT (HSPI) — SAME driver as the C3 board, different pins ---
#define TFT_CS   15
#define TFT_DC    2
#define TFT_RST  -1   // tied to the board reset on this carrier
#define TFT_MOSI 13
#define TFT_SCLK 14
#define TFT_BL   21   // backlight: driven HIGH in setup(), else the panel stays black
// Some dual-USB CYDs ship with an ILI9341 panel instead of the ST7789. The ST7789
// init drives it fine, but its MADCTL reads differently: mirrored image, red/blue
// swapped. Set CYD_ILI9341 1 (board_local.h, or -D from the cyd-ili9341 env) for
// those boards; the firmware then writes the ILI9341 orientation (applyRotation()).
#ifndef CYD_ILI9341
#define CYD_ILI9341 0
#endif

#else
#  error "POCKETOBI_BOARD must be BOARD_LXT_C3 or BOARD_CYD"
#endif

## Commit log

2026-07-21 Updated after description issues
    [PocketOBI.ino]
2026-07-29 Add write logging + fix charger-lock status display
    - COMM_DEBUG now traces the raw frame write/store (ow33), so unlock writes
    are visible on serial.
    - Home and Details LOCKED/UNLOCKED now reflect the real charger lock
    (nybble 34 / CS0 / CS2), not only the failure code. Details shows a
    ChgLock line with the causes.
    [PocketOBI.ino]
2026-07-30 Fix temperature decoding (1/10 K, not Celsius x100)
    Cell/MOSFET temperature is decoded as raw/10 - 273.15 per the documented
    protocol (rosvall / obi-esp32). Previous /100 was a few degrees off on a
    healthy pack and masked faulty-thermistor readings: an out-of-range sensor
    (which the charger rejects as a "temperature" fault) now shows its true
    value (e.g. ~ -30 C) instead of a misleading normal-looking number.
    [PocketOBI.ino]
2026-07-30 Flag implausible temperature (likely faulty thermistor)
    When the cell temperature is outside a plausible window (-20..80 C), the home
    temperature chip turns red and shows a trailing "?" (e.g. "T -30?"). This very
    likely indicates a faulty thermistor - the charger rejects such a pack as a
    "temperature" fault. Shown as a suspicion (the "?"), not a confirmed diagnosis.
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2026-07-30 Release hardening pass (v0.9.4)
    Pre-release audit against all protocol sources (makita_lxt.py, rosvall,
    synrais, ArduinoOBI):
    - PC bridge reports the real firmware version (was 0.8.x).
    - F0513: clear romId/msg so Debug/raw does not show stale data.
    - 10-cell / 36V packs (BL36xx) detected and shown as unsupported (18V only).
    - Guard a uint8_t underflow if a 0x33 command had rsp_len < 8.
    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
2026-07-31 Add architecture + wiring diagrams and detailed wiring tables to README
    - Architecture section (block diagram) and Wiring section (physical diagram),
    each shown as a clickable thumbnail linking to the full-size file in docs/.
    - Detailed wiring tables: ESP32-C3 <-> TFT/encoder module, and ESP32-C3 <->
    Makita LXT battery adapter, plus pull-up and DATA/ENABLE-identification notes.
    - docs/ folder with instructions for the two image files to drop in.
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2026-08-02 Show both temperature sensors; neutral labeling; tidy release wording… (#2)
    * Show both temperature sensors; neutral labeling; tidy release wording (v0.9.5)
    - Home temperature chip shows both BMS sensors (e.g. 28/31) instead of one, red
    when either reading is implausible, so a disagreement is visible at a glance.
    - Stop claiming which reading is the cell vs the MOSFET sensor: the mapping is
    undocumented (OBI labels them Sensor 1/2); README, code comments and the UI
    now present them neutrally.
    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
2026-08-02 Add PlatformIO build (mirror of Arduino sources) - v0.9.6
    - New platformio/ project (conventional src/ + lib/OneWire2/), board
    esp32-c3-devkitm-1, ARDUINO_USB_CDC_ON_BOOT=1, Adafruit GFX/ST7789 +
    RotaryEncoder as lib_deps.
    - The PlatformIO sources are a MIRROR of the root Arduino sketch; the root
    PocketOBI.ino stays the single source of truth. sync.ps1 / sync.sh
    regenerate platformio/src + platformio/lib.
    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
2026-08-03 platformio: add ARDUINO_USB_MODE=1 so Serial compiles on ESP32-C3
    The C3's native USB needs both ARDUINO_USB_MODE=1 (built-in USB Serial/JTAG)
    and ARDUINO_USB_CDC_ON_BOOT=1 to map `Serial`; with only the latter, `Serial`
    is undefined at compile time (reported on PlatformIO build).
2026-08-04 HARDWARE: switch carrier connectors to JST-PH + 3.5mm terminal block
    J3 battery signal plug: JST-XH (2.50mm) -> JST-PH (2.00mm, B6B-PH-K top entry).
    J4 GND terminal: 5.08mm -> 3.5mm (Phoenix MC-1,5-2-3.5). Docs only, no firmware change.
2026-08-04 Details: add SoH estimate + protection thresholds; strengthen temp note
    (a) Temperature: README note and code comment upgraded from 'disputed' to
    'well-supported' - 1/10 K now corroborated by 4 sources (rosvall, obi-esp32,
    and both the reader and BMS emulator of the m5din-makita fork).
    (b) Details (standard packs): add Health~ (cycle-based SoH estimate) and
    Prot OL/OD (over-current / over-discharge protection thresholds), decoded from
    the ROM message frame already read - no extra bus traffic. Decodes corroborated
    by both sides of the m5din-makita fork. Absolute figures not yet bench-verified.
    Bump FW_VERSION 0.9.6 -> 0.9.7, changelog, PlatformIO mirror synced.
    [PocketOBI.ino]
2026-08-04 Details: dual capacity-format decode + document secondary checksums (drakosha)
    Pulled from the MIT-licensed drakosha/makita-battery-tools:
    - Capacity (frame byte 16) now decoded for both encodings: newer packs store it
    directly in whole Ah, older packs store nibble-swap in tenths of an Ah.
    - Documented the two secondary frame checksums (CS3/CS4 in byte 31, covering
    bytes 22-23 and 24-30). No behaviour change; note that any future write to
    bytes 22-30 must recompute byte 31. Their primary-checksum decode matches ours.
    - CLAUDE.md: added m5din-makita (#5) and drakosha (#6) to the reference repos.
    [PocketOBI.ino]
2026-08-05 Release v1.0.0 — first stable release
    - Flag a faulty temperature sensor explicitly on the home chip ("!" prefix,
    red) = suspected hardware fault, not a real extreme temperature.
    - Temperature unit (1/10 K) validated on real packs; comments updated.
    - Bump FW_VERSION to 1.0.0 + CHANGELOG.
2026-08-06 Relicense under PolyForm Noncommercial 1.0.0
    - LICENSE: full, verbatim PolyForm Noncommercial 1.0.0 text + Required Notice
    (Copyright (c) 2026 TheRepairForge).
    - THIRD-PARTY.md: MIT notices for the bundled OneWire2 library and the upstream
    Open Battery Information project (not covered by PolyForm).
    - SPDX-License-Identifier headers on the sketch; README license section updated.
    - No firmware behaviour change (FW_VERSION unchanged).
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2026-09-05 Release v2.1.0 — V2 interface on a single-source build
    First public release since v1.0.0. Ships the V2 interface (2x2 launcher,
    staged repair wizard, multilingual EN/FR/DE/ES, on-device extended reads),
    developed internally as 2.0.0, on the restructured single-source build:
    one source tree at the repo root, compiled by both the Arduino toolchain
    and PlatformIO via the root platformio.ini (src_dir = .). The generated
    platformio/ mirror and its sync scripts are removed.
    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
2026-09-05 hardware: publish fabrication files (Gerbers, schematic, BOM) for the bench-validated carrier PCB
    Gerbers = the fabricated 2026-08-05 set (the physically-tested board); schematic PDF + BOM
    exported from KiCad. CC BY-NC-SA 4.0. Enclosure on Printables by link. Pinout stays in HARDWARE.md.
    [PocketOBI-HW-BOM.csv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]
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2026-09-18 LXT: retire the D6 latched-fault marker from the verdict (D24) — v2.1.1
    Public 2.1.x hotfix. Same fix as feature/v2.3, re-applied to the monolith: the D6
    markers (0x58D/0x309) are the BL1850B resting constant, not a per-pack fault (two
    healthy BL1850B units read an identical 0x0B/0x49). The old rule flagged every
    BL1850B as latched -> a false SUSPECT (issue #13).
    - readExtended(): stop deriving latchedFault; keep the raw bytes in faultMkA/faultMkB
    - computeVerdict(): drop the latched -> SUSPECT path; a genuinely latched pack is
    still caught by its charger lock (nibble=3 -> REPAIRABLE)
    - Debug screen: show raw faultMk XX/XX instead of the derived YES/no
    - FW_VERSION 2.1.0 -> 2.1.1, CHANG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
    [PocketOBI.ino]
2026-09-24 Modernize README with centered header and badges
    Adds a centered title/tagline/badge header (release, license,
    platform, build tooling) and a nav row, matching the PackScope
    README. Also fixes the Status section which still said v2.1.0
    despite v2.1.1 being the current release.
2026-10-01 hardware: schematic PDF updated 2026-09-30 (PCB and Gerbers unchanged); fix the truncated Revision sentence
2026-10-01 release(2.2.0): CYD alternative board with touch UI
    Adds the CYD (ESP32-2432S028R, XPT2046 resistive touch) as a second,
    alternative carrier board next to the ESP32-C3 product. Same firmware
    logic and screens; the board is chosen at build time (board_config.h,
    one PlatformIO env per board: esp32-c3, cyd). Touch-driven UI with
    on-device calibration (Settings > Calibrate).
    Includes the 2.1.1 fix. README covers the CYD wiring (CN1) and builds.
    [PocketOBI.ino, board_config.h]
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2026-10-07 docs(cyd guide): 470 ohm pull-ups, the value the CYD was bench-validated with
2026-10-07 docs(cyd): 470 ohm CN1 pull-ups in README and CYD_NOTES, the bench-validated value
2026-10-07 docs(cyd guide): annotated board photo (BOOT, CN1, USB); BOOT location corrected
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2026-10-07 docs: 470 ohm pull-ups in the C3 BOM and wiring table, the bench-validated value (#20)
2026-10-08 release(2.3.0): Japanese build, new logo, prebuilt binaries
    - Japanese on every screen (ENABLE_CJK; envs esp32-c3-ja, cyd-ja), an unreviewed
    first draft with a call for native reviewers; Noto Sans JP + Fusion Pixel glyphs (OFL)
    - CYD touch-calibration screen translated (FR/DE/ES/JA)
    - New PocketOBI logo on the splash and About screens
    - Firmware source split into modules (no behaviour change)
    - tools/hostsim: render every screen on a PC, per language and board
    - Translation issue form + docs/TRANSLATING.md (DE/ES/JA)
    - README: flash a prebuilt binary; releases now carry binaries + SHA256SUMS
    [PocketOBI.ino, bridge.cpp]
2026-10-08 release(2.3.1): CYD_ILI9341 option for CYDs with an ILI9341 panel (#18), OneWire2 warnings
    Port of fix/cyd-ili9341 (written on the 2.2 monolith) to the 2.3 modules: applyRotation()
    in display.cpp, called from setup() and Settings > Flip. cyd-ili9341 env and release binary,
    CYD guide entry (colour wording from the reporter), README binary table. FW_VERSION 2.3.1.
    [OneWire2.cpp, PocketOBI.ino, board_config.h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]
2026-10-19 release(2.5.0): new interface, Asia build (Japanese, Korean, Vietnamese), safer CYD confirms
    - New interface on every screen: shared components, footers that say what the controls do,
    clear status words; Battery, Repair, Tools, Settings, Comm error, PC bridge, Debug, About.
    - Asia build (esp32-c3-asia / cyd-asia, was -ja): EN + Japanese + Korean + Vietnamese.
    Korean is a first draft, review welcome.
    - CYD: only the primary button confirms a pack write.
    - A corrupted read (cell > 5 V, pack > 22 V) is a comm error, not a hardware verdict (#16).
    - Reset error result says NOT RE-READ when the re-read failed; F0513 date carry-over fixed;
    faster give-up with no pack.
    - Screen-demo builds for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
2026-10-22 release(2.5.1): read-only 14.4 V LXT packs (#28), honest unlock caveat on older (F0513) packs
    - 14.4 V LXT packs (model BL14xx) are read as 4 cells: cell bars, type
    "LXT 14.4V", checks and verdict on four. Unlock and error reset are not
    offered on them (not validated); a charger lock reads LOCKED. A pack whose
    model can't be read stays 5 cells. Bridge contract byte 2 stays 5 for LXT.
    - Unlock confirm: a yellow caveat on packs read through the F0513 cell path
    (the unlock is not validated on that generation); the button stays.
    - FW_VERSION 2.5.1, bridge version triplet 2/5/1, CHANGELOG 2.5.1.
2026-10-25 Show a "Connecting..." toast while the pack is read (#33)
    A non-blocking "Connecting..." banner is shown before each pack read or
    write (Battery, Repair, refresh, Tools reset and debug reads, error reset),
    so the screen no longer looks frozen while the pack answers.
    Strings in EN/FR/DE/ES and JA/KO/VI.
    Contributed by @scp38; follow-up kept the shipped Japanese font tables and
    gave toast() a default blocking argument.
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2026-10-27 README: running the ES3C28P from a LiPo cell is not tested yet
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

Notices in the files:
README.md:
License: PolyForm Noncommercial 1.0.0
